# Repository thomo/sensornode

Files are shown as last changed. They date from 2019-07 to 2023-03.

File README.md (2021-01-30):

# SensorNode

A ESP8266 based solution with support for

- DS18B20 1-Wire temperature sensor
- BME280 humidity, pressure, temperature sensor (I2C) - Note: temperature is measured in-chip, so it is usually too inaccurate to measure the environment temperature
- Si7021 humidity, temperatur sensor (I2C)
- HTU21 humidity, temperatur sensor (I2C)
- LDR sensors to "measure" the brightness (analog)

The software will determine which sensors are connected. Because of the fixed I2C addresses on the sensors only one example of BME, Si7021, or HTU21 can be connected - but multiple different. Multiple 1-Wire sensors are supported. In total the number of sensors is set to 10 (`main.cpp`__MAX_SENSORS__) - but please note that each measurand counts, e.g. a BME280 counts 3x.

The software provides an configuration web page where the sensors can be enabled and an location can be specified.

The ESP will than read the sensors every 10 seconds (can be changed in ~~`main.cpp` __FETCH_SENSORS_CYCLE_SEC__~~ config dialog). The values are published via MQTT (`main.cpp` __MQTT_SERVER__). The used MQTT topic can be configured by the configuration web page (see below).

## Compile time configuration

There are some values which are only configureable on compile time (in `main.cpp`).

- DEFAULT_NODE_NAME (= F42-NODE) - used as WiFi SSID
- MQTT_SERVER (= mqtt.thomo.de) - the MQTT server, you will have to use your own :wink:
- ~~ALTITUDE (= 282.0F) - your local altitude in meters, used to adjust the pressure measurement~~ (configurable in the config dialog)
- DEFAULT_ROOT_TOPIC (= "tmp") - the standard root topic
- ~~FETCH_SENSORS_CYCLE_SEC (= 10) - fetch the sensor values every 10 seconds~~
- MAX_SENSORS (= 10) - number of supported sensors

## Runtime configuration

The runtime configuration is done by using a configuration web page served by the node. Just enter *`http://<node-ip>`*.

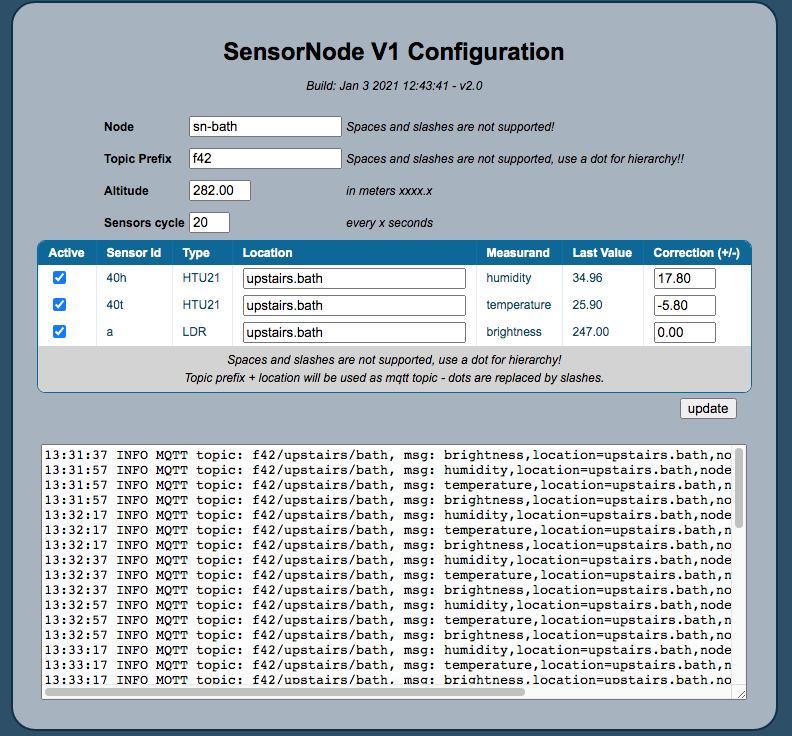
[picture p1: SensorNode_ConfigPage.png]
Configuration page


The config dialog allows you to enable/disable (aka activate) the connected sensors, only active sensor values are MQTT published.
For each sensor a location can be defined and a correction value. The correction value is add/sub from the sensor value and is used to calibrate the sensor.

*Note:* The displayed sensor value and the value published at MQTT already include the correction value.

## API

The Sensor Node offers some URIs

- `http://<node-ip>/config` - the node name, root topic, altitude, and display flag, as JSON data
- `http://<node-ip>/sensors` - the sensor data, as JSON

## MQTT Topic and Payload

The node will acquire the sensor measurements every X seconds - wether or not the sensor is enabled. It will than publish the value to the MQTT server with:

- topic: `<root topic>/<location>` - where each dot '.' in the root topic and in location is replaced by a slash.
  
  E.g.: with root topic *homebase* and sensor location *ground.kitchen* the resulting topic is `homebase/ground/kitchen`.
- payload: `<measurand>,location=<sensor location>,node=<node name>,sensor=<sensor type> value=<sensor value>`

  E.g.: for the selected DS18B20 sensor above the payload is `temperature,location=upstairs.workroom,node=f42,sensor=DS18B20 value=25.25`

## Circuit and PCB designs

### Sensors

- I2C Sensors
  - SDA -> GPIO4 (D2)
  - SCL -> GPIO5 (D1)
- 1wire
  - DATA -> GPIO0 (D3)
- LDR
  - ADC (Pin2)

### Display

- ST7735 -> ESP8266
  - 1 - RST -> RST or +3V3
  - 2 - CS  -> GPIO15 (D8)  
  - 3 - D/C -> GPIO2 (D4)
  - 4 - DIN -> GPI13 (D7)
  - 5 - CLK -> GPI14 (D5)
  - 6 - VCC -> +3V3
  - 7 - BL  -> +3V3
  - 8 - GND -> GND

__Note:__ _GPIO12 (D6) is not connected but is part of the SPI interface._

### SensorNodeUsb

It is a board to be used with the sensor node code. The board is designed to be simply plugged in an USB port.

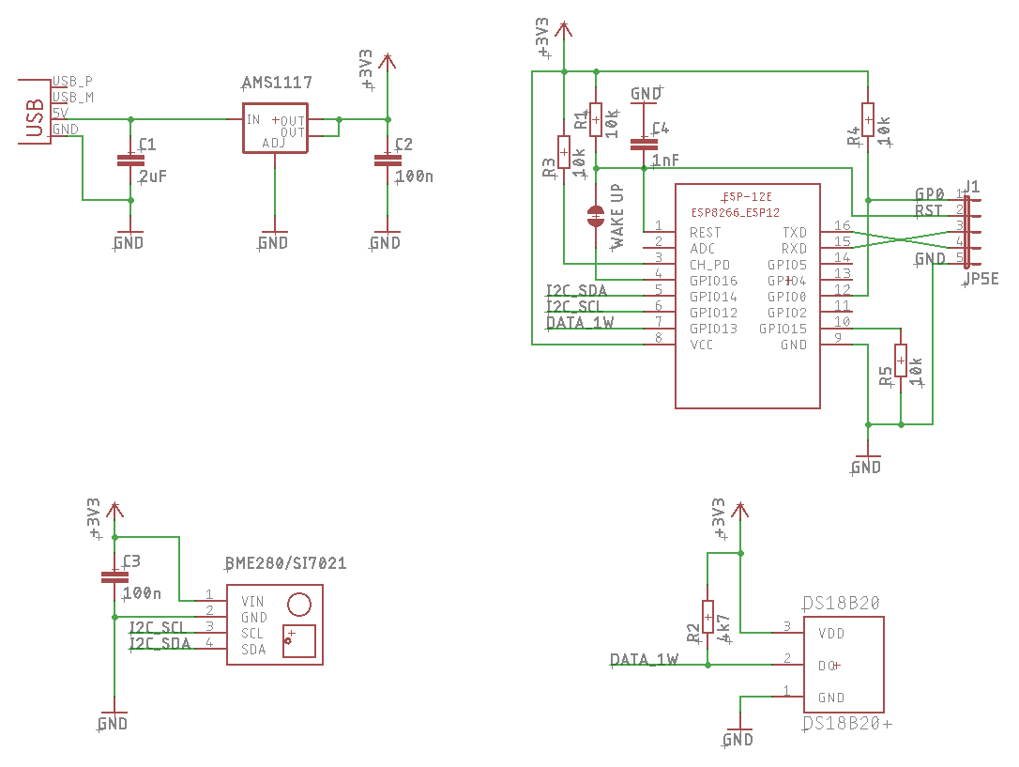
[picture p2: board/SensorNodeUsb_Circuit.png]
Circuit SensorNodeUsb circuit


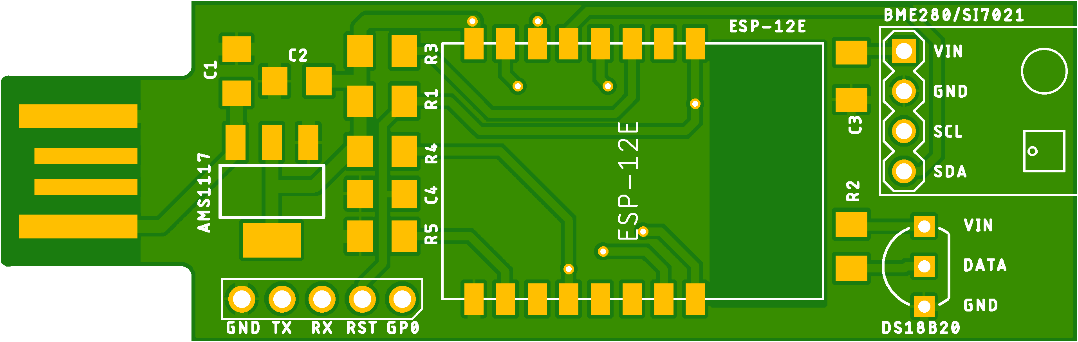
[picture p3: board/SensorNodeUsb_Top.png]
PCB top layer SensorNodeUsb PCB top layer


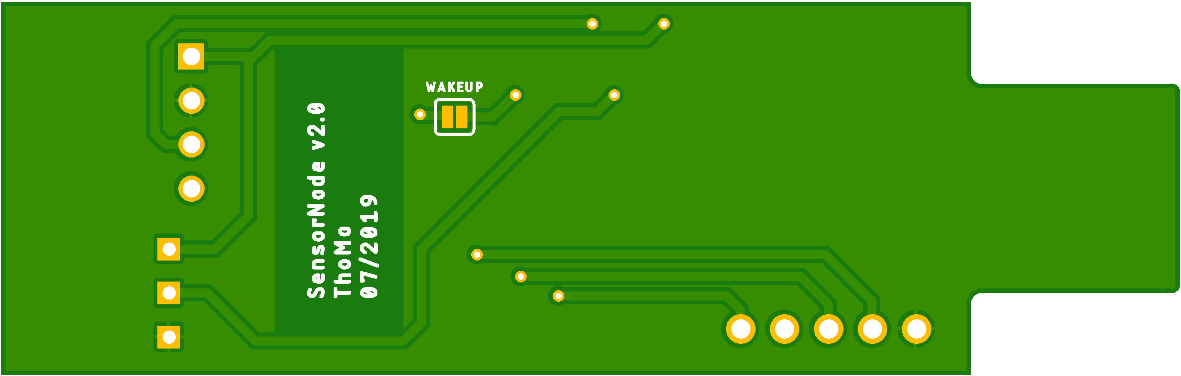
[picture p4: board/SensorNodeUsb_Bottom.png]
PCB bottom layer SensorNodeUsb PCB bottom layer


If you want to order some pcb boards you can use this link to [Aisler](https://aisler.net/p/KDLFHCIK).

### SensorNodeCat

Another board I designed to be placed in a CAT box, but it can also be used in a more general way.

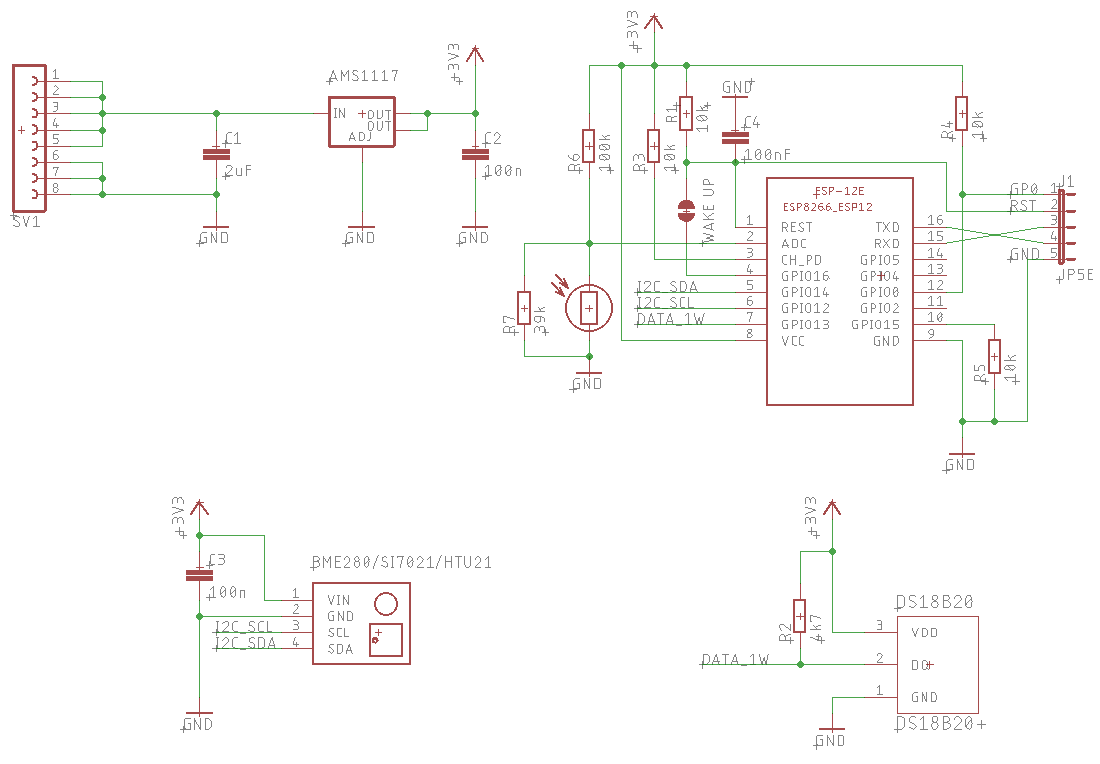
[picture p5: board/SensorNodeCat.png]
Circuit SensorNodeCat circuit


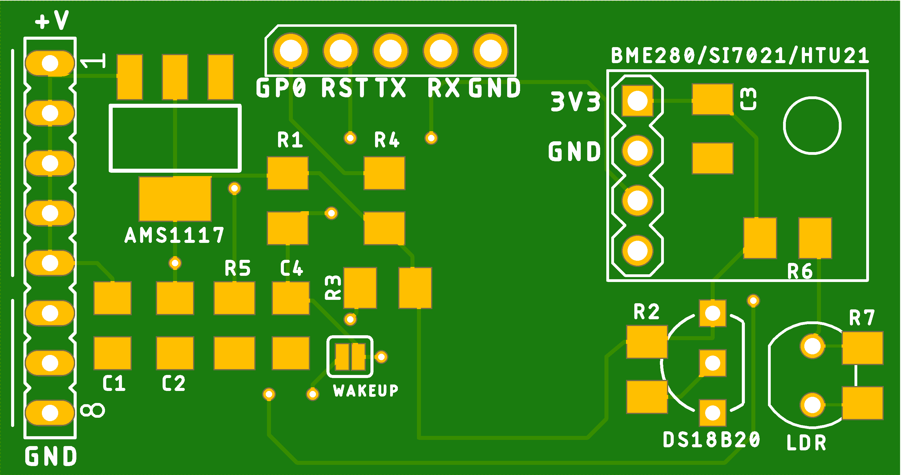
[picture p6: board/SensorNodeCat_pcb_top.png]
PCB top layer SensorNodeCat PCB top layer


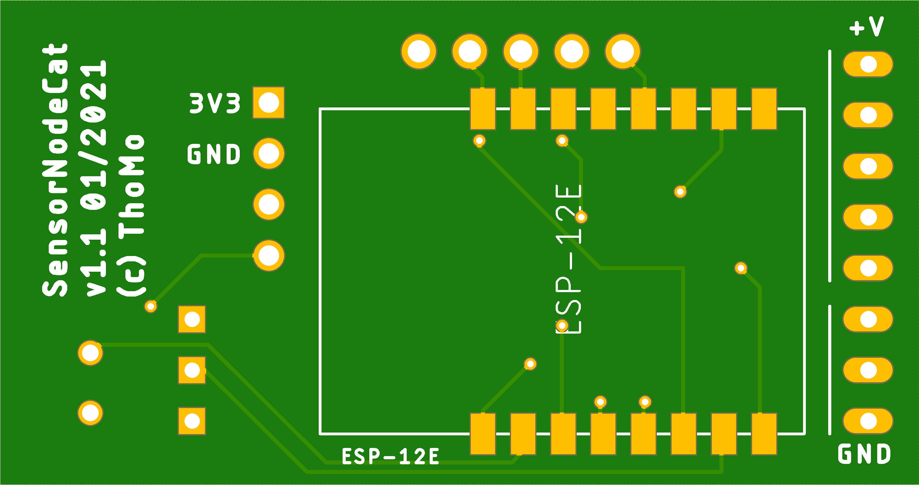
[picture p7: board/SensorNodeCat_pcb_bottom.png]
PCB bottom layer SensorNodeCat PCB bottom layer


If you want to order some pcb boards you can use this link to [Aisler](
https://aisler.net/p/CNWEPDIW).

## Fonts/Icons

- Font: [Landasans](https://www.fontspace.com/search?q=landasans)
- Icons:
  - https://iconarchive.com/search?q=weather&page=6
  - https://www.elegantthemes.com/blog/freebie-of-the-week/beautiful-flat-icons-for-free
  - http://paomedia.github.io/small-n-flat/

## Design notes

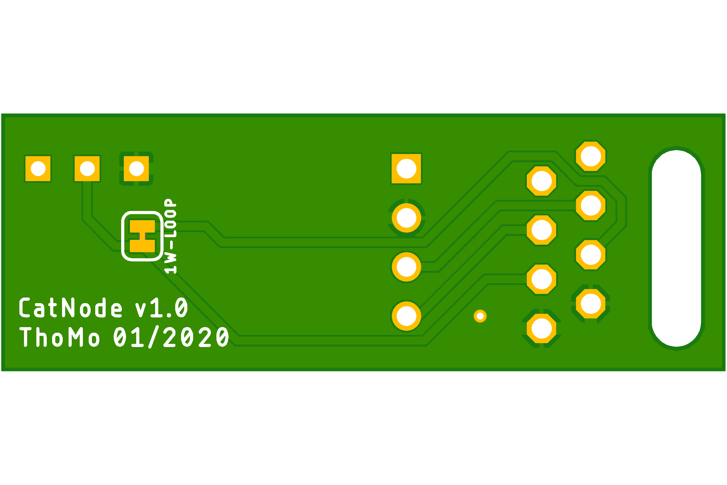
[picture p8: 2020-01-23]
board/CatNode_pcb_bottom.png

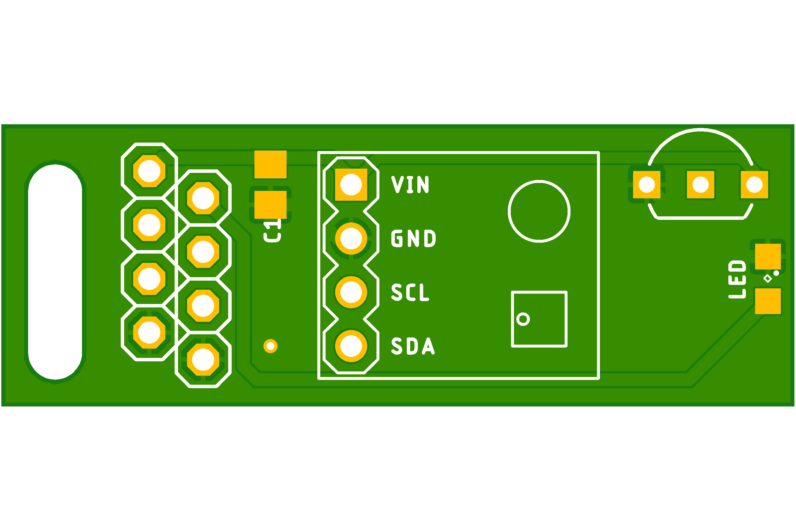
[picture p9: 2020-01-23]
board/CatNode__pcb_top.png

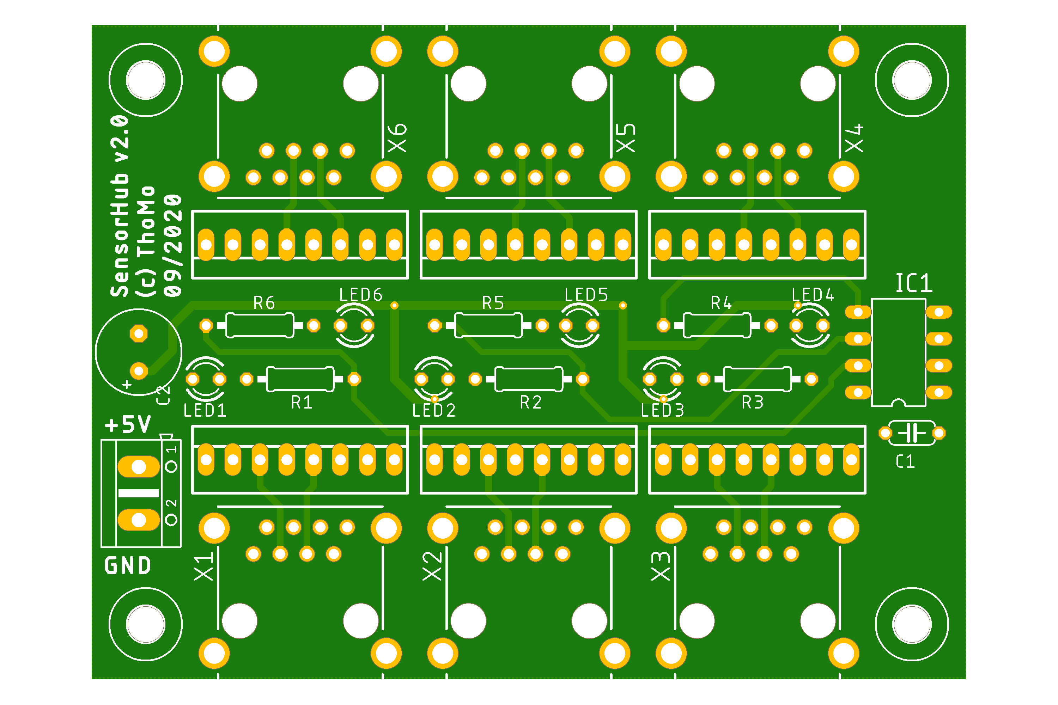
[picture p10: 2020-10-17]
board/SensorHub_pcb_top.png

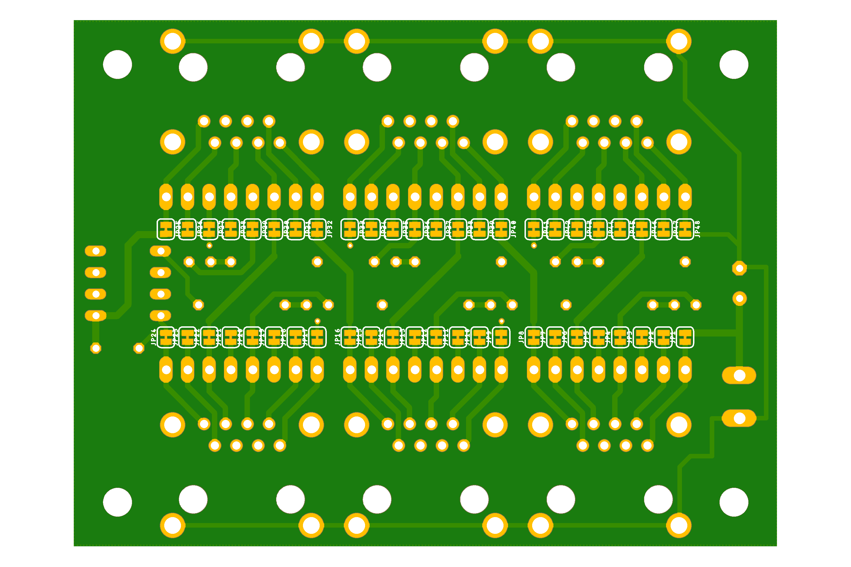
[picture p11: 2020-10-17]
board/SensorHub_pcb_bottom.png

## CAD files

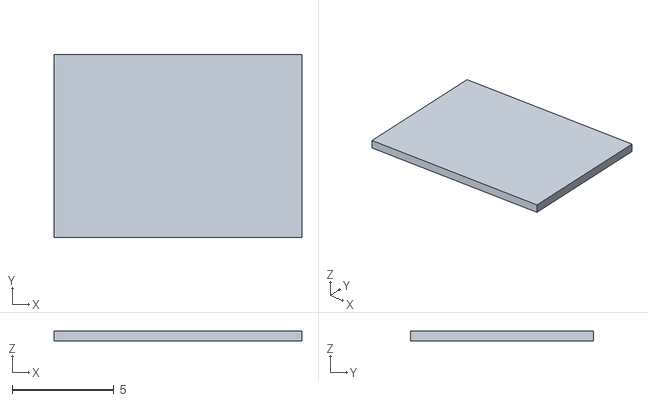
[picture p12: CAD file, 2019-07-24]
3d/usbspacer.stl
12.2 x 9.00 x 0.5

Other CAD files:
3d/usbspacer.blend

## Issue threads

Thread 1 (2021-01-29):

Quesrtions about the PCB

JPFrancoia, 2021-01-29:
Hi,

I looked at your project and it looks very good. I'm no expert at reading PCB design, so I figured I might ask you directly:

- Is there any way to link the Vin pin of the I2C sensor to a GPIO of the board (to limit power consumption) ?
- Is it possible to power the PCB with a battery?

I really like the compactness of the PCB, and the USB interface. It would be super practical to make a small sensor: no hanging wires since the I2C sensor is soldered directly on the board, and very easy to upgrade the code through USB (I can 3D print a case to just expose the usb).

Kind regards

thomo, 2021-01-30:
Hi,
1) I didn't try it but I assume it should be possible. You could just try to cut the trace above pin8 of ESP which goes to the sensors and connect the senors side to GPIO2.
2) Sure - please check the SensorNodeCat board (in folder board). It is even more compact.

JPFrancoia, 2021-01-30:
Perfect, thank you very much!

Closed 2021-01-30.

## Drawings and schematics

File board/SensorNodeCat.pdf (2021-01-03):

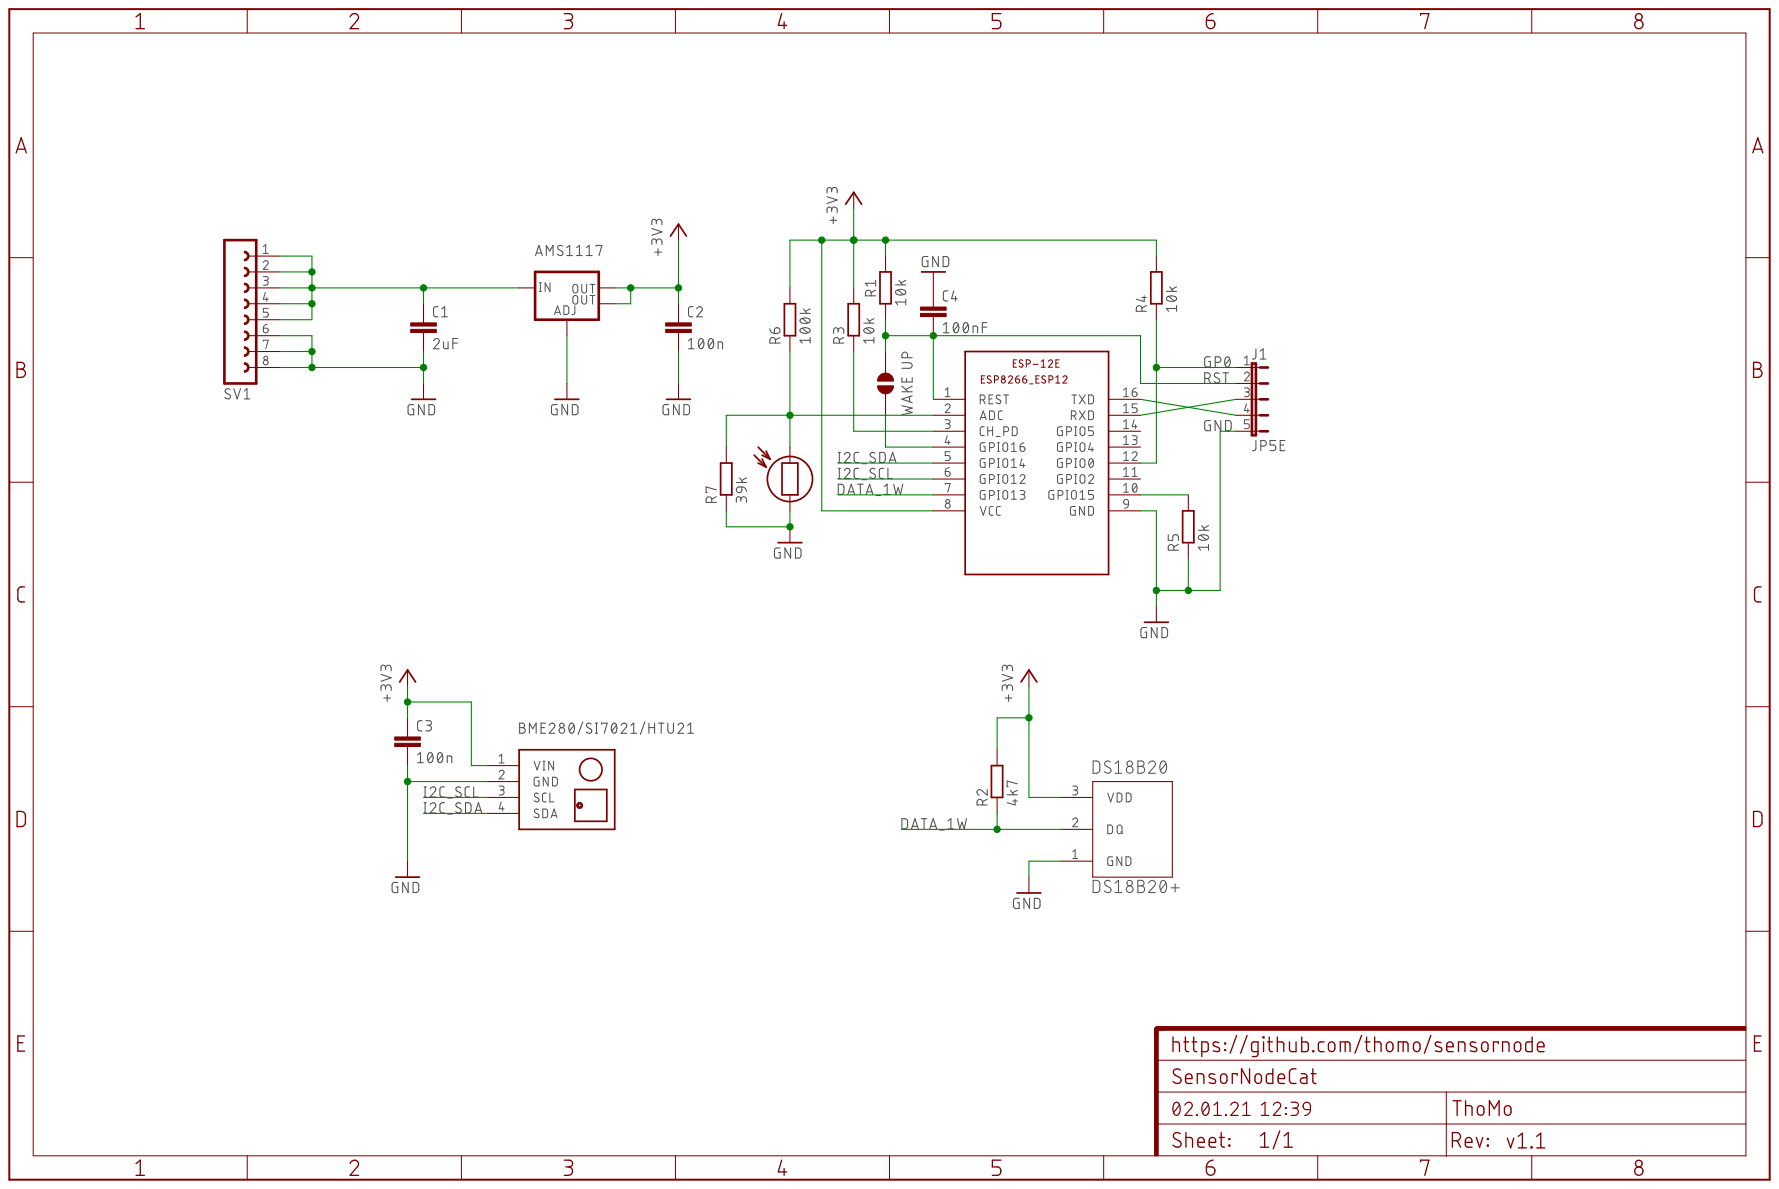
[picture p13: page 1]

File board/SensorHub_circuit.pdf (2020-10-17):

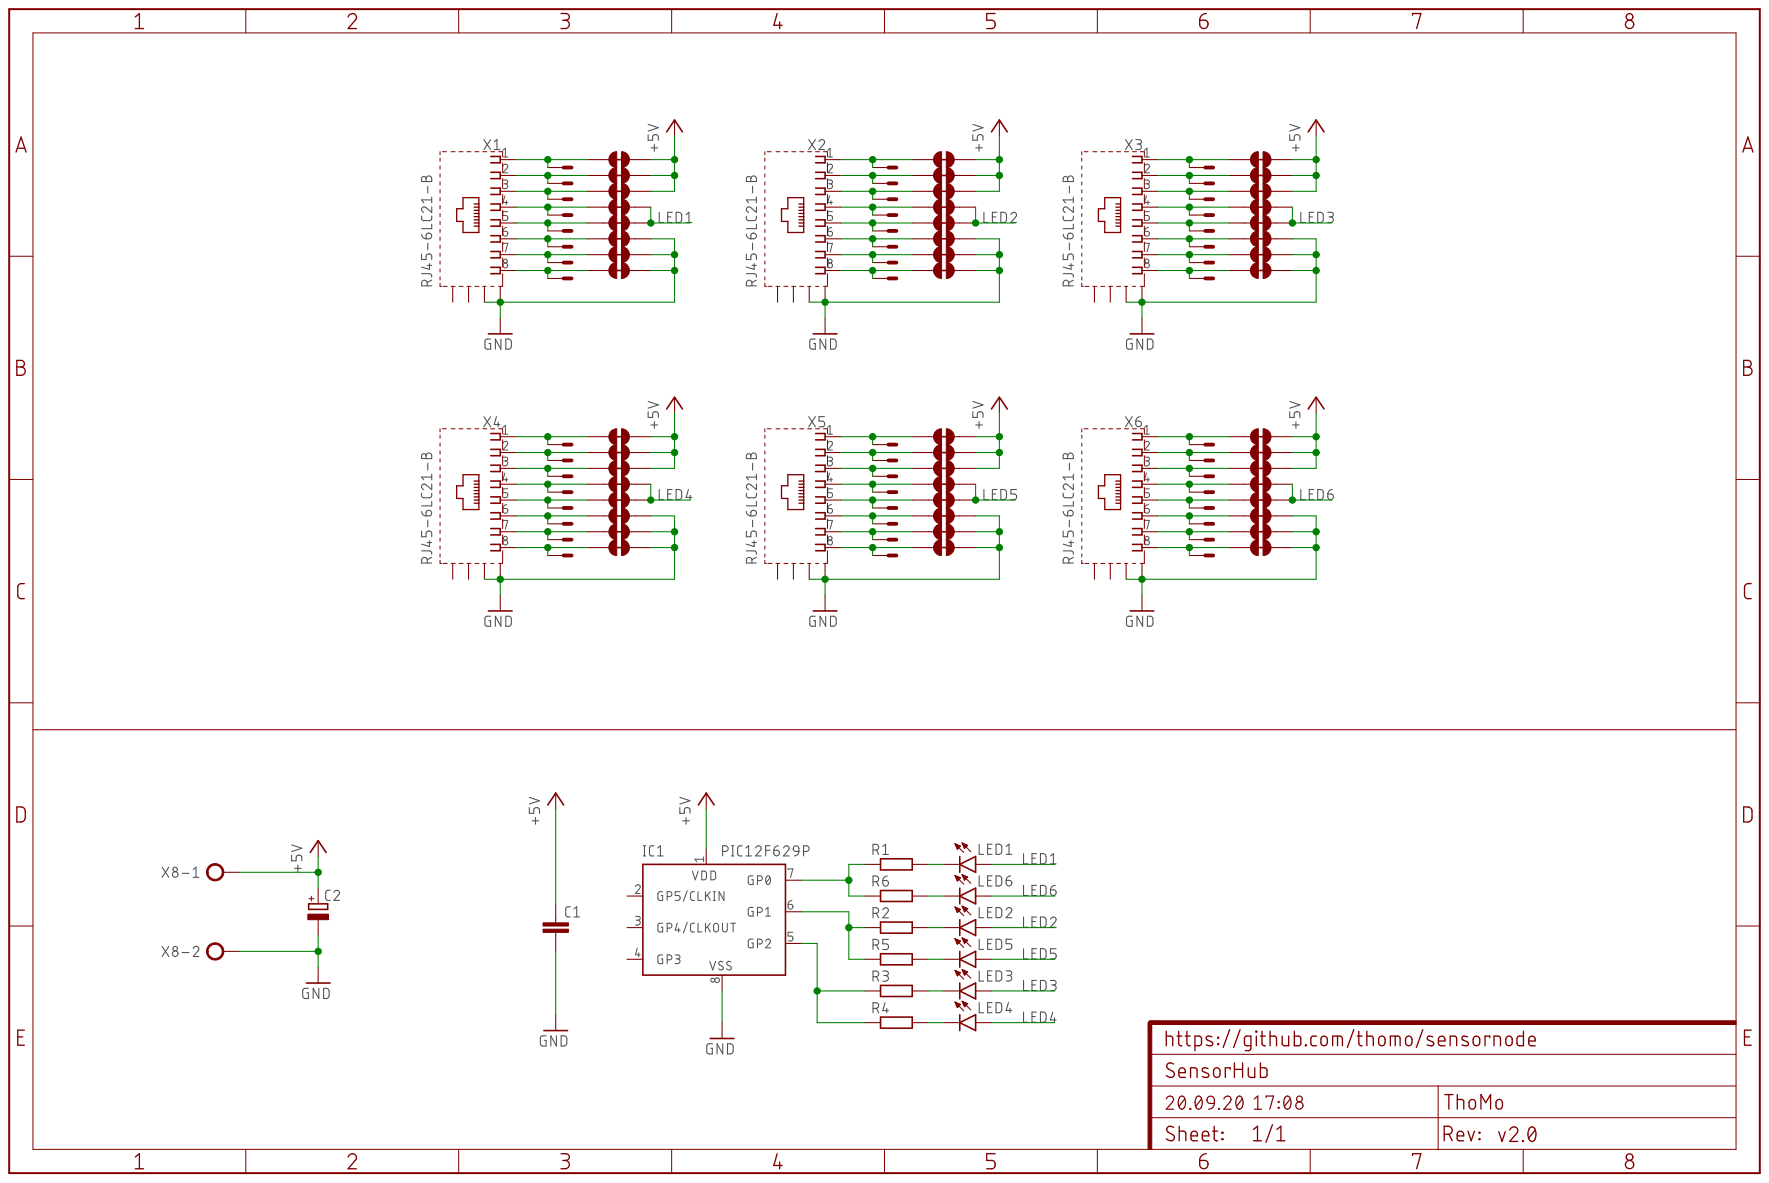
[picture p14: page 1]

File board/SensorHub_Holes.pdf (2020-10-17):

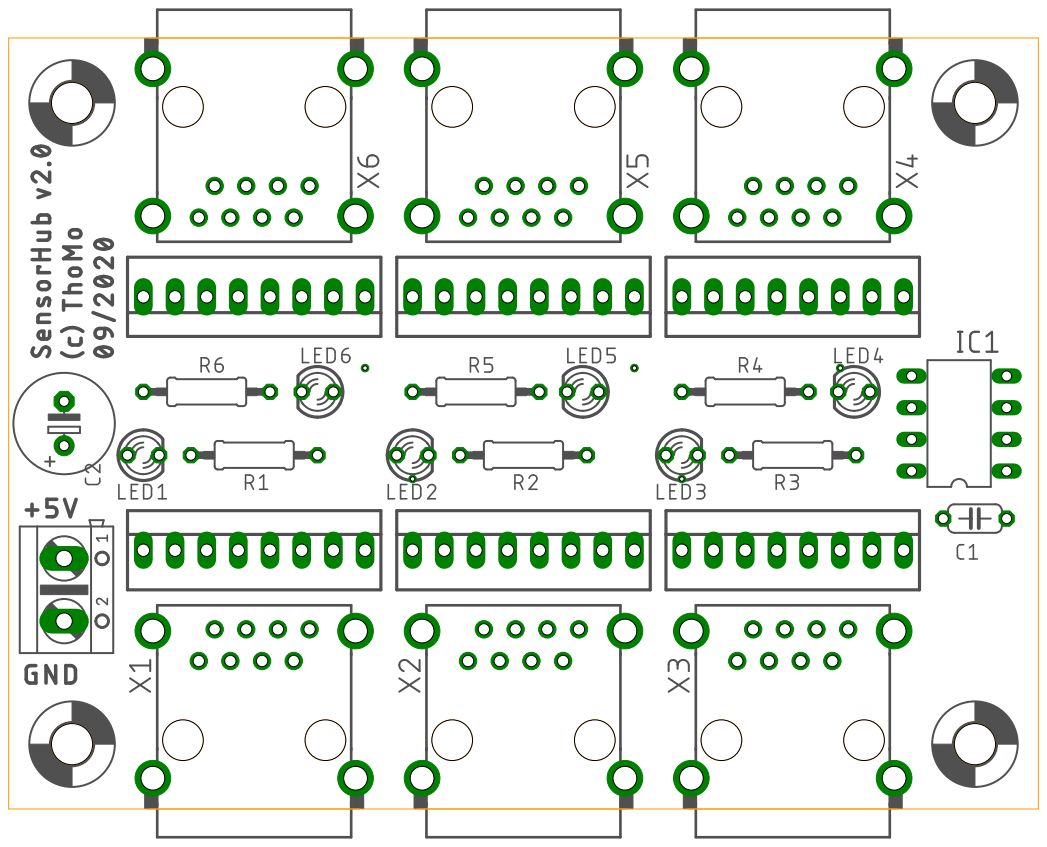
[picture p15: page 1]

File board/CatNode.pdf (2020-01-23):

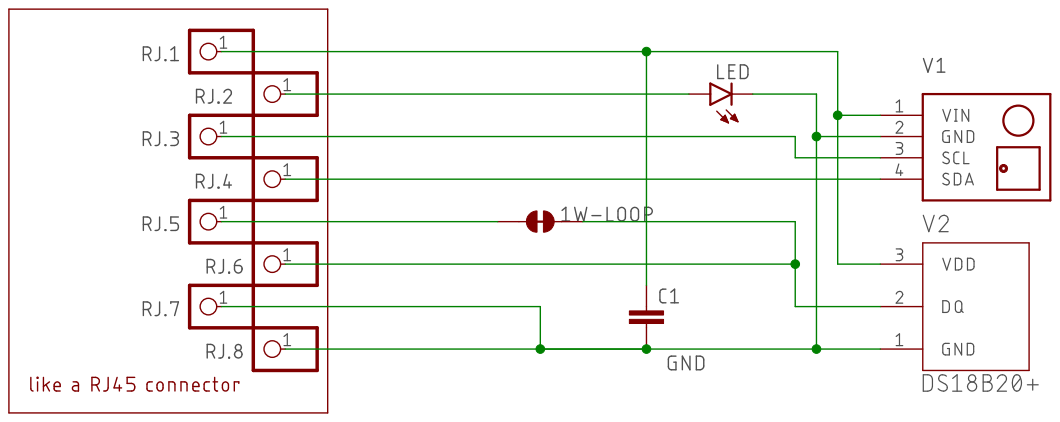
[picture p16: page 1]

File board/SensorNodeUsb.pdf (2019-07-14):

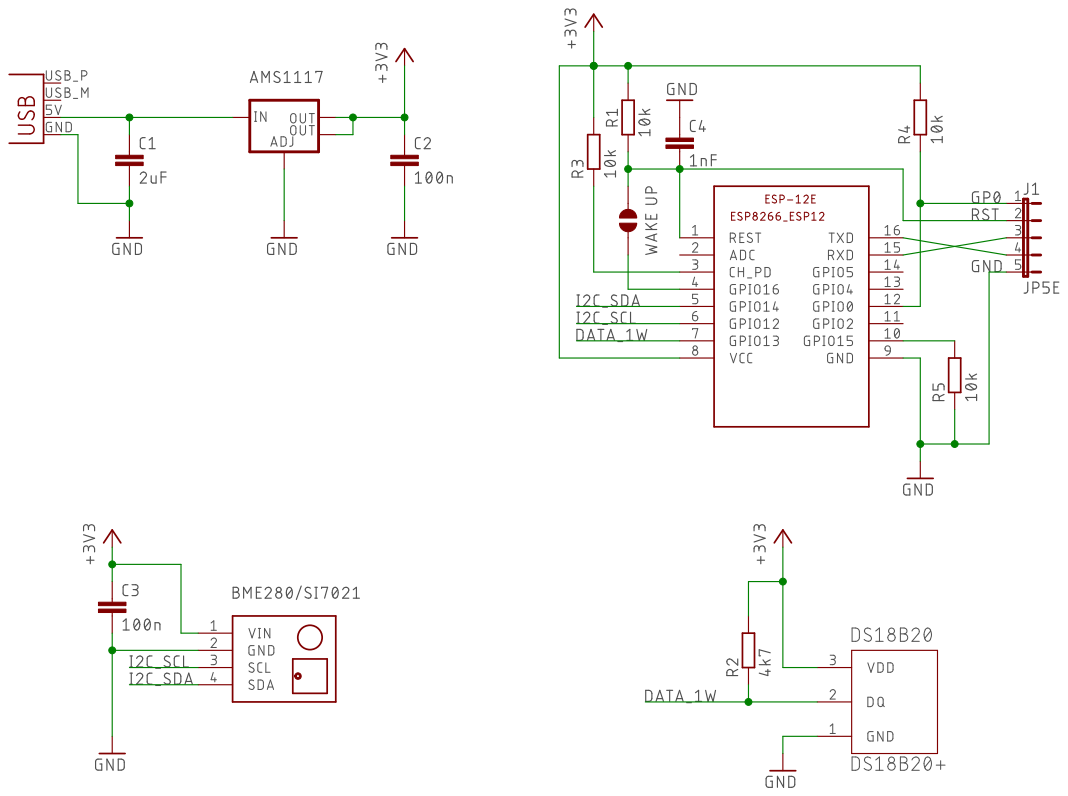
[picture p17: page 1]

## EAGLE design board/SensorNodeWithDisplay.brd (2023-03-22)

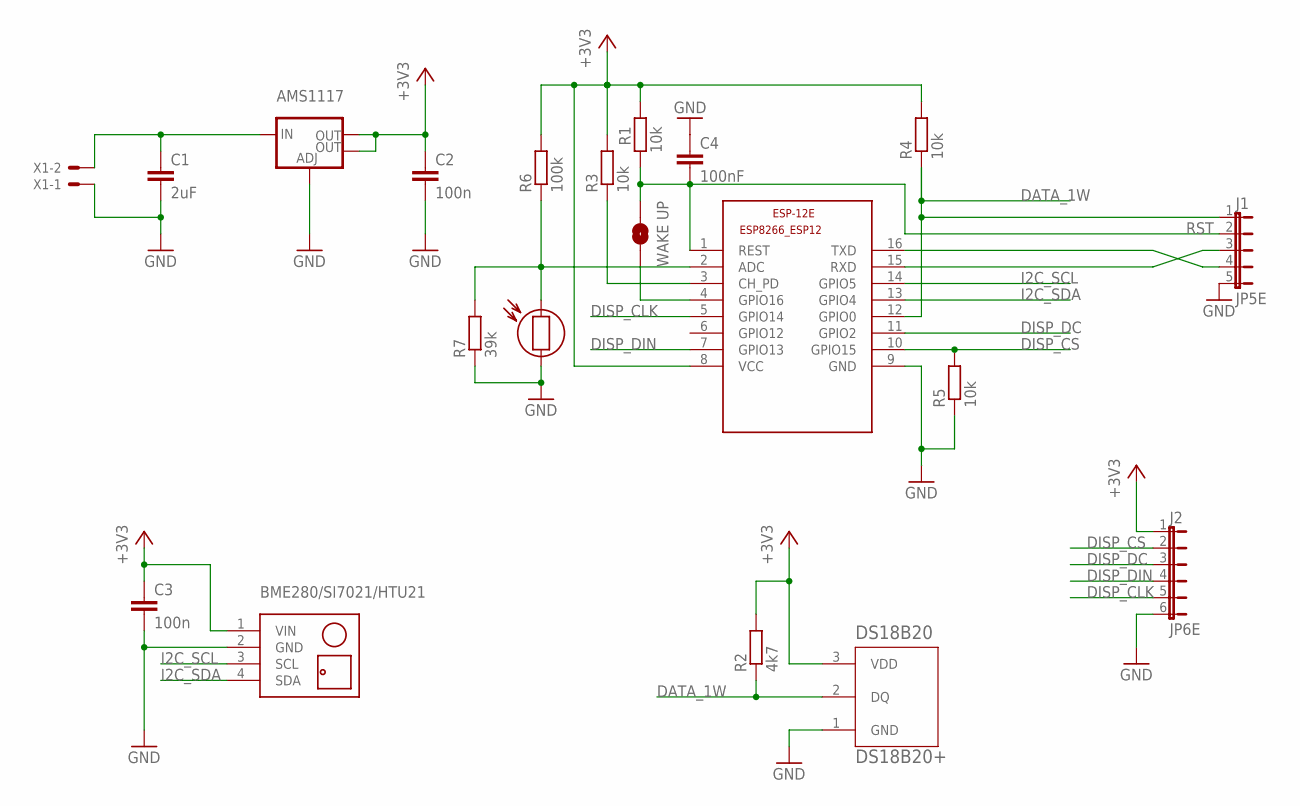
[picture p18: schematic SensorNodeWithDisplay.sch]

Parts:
AMS1117: V_REG_LM1117SOT223; SOT223
BME280/SI7021/HTU21: BME280
C1: 2uF; C1206
C2: 100n; C1206
C3: 100n; C1206K
C4: 100nF; C1206
DS18B20: DS18B20+; TO-92
ESP-12E: ESP8266-12; ESP8266-ESP12
J1: JP5E; JP5
J2: JP6E; JP6
LDR: LDR-GL55XX; GL55
R1, R3, R4, R5: 10k; M1206
R2: 4k7; M1206
R6: 100k; M1206
R7: 39k; M1206
WAKEUP: WAKE UP; SMT-JUMPER_2_NO_SILK
X1: JST-XH-02-PIN-LONG-PAD; JST-XH-02-PACKAGE-LONG-PAD

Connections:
+3V3: AMS1117.2 (OUT), AMS1117.4 (OUT), BME280/SI7021/HTU21.1 (VIN), C2.1, C3.1, DS18B20.3 (VDD), ESP-12E.8 (VCC), J2.1, R1.1, R2.2, R3.2, R4.2, R6.2
DATA_1W: DS18B20.2 (DQ), ESP-12E.12 (GPIO0), J1.1, R2.1, R4.1
DISP_CLK: ESP-12E.5 (GPIO14), J2.5
DISP_CS: ESP-12E.10 (GPIO15), J2.2, R5.2
DISP_DC: ESP-12E.11 (GPIO2), J2.3
DISP_DIN: ESP-12E.7 (GPIO13), J2.4
GND: AMS1117.1 (ADJ), BME280/SI7021/HTU21.2 (GND), C1.2, C2.2, C3.2, C4.1, DS18B20.1 (GND), ESP-12E.9 (GND), J1.5, J2.6, LDR.2, R5.1, R7.1, X1.1
I2C_SCL: BME280/SI7021/HTU21.3 (SCL), ESP-12E.14 (GPIO5)
I2C_SDA: BME280/SI7021/HTU21.4 (SDA), ESP-12E.13 (GPIO4)
unnamed: ESP-12E.15 (RXD), J1.3
unnamed: ESP-12E.4 (GPIO16), WAKEUP.1
unnamed: ESP-12E.3 (CH_PD), R3.1
unnamed: ESP-12E.16 (TXD), J1.4
unnamed: ESP-12E.2 (ADC), LDR.1, R6.1, R7.2
unnamed: AMS1117.3 (IN), C1.1, X1.2
RST: C4.2, ESP-12E.1 (REST), J1.2, R1.2, WAKEUP.2

Board: 2 copper layers, 24 parts (0 on the bottom side), 16 nets, no tracks yet.

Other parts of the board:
U$1, U$2, U$3, U$5: 3,0

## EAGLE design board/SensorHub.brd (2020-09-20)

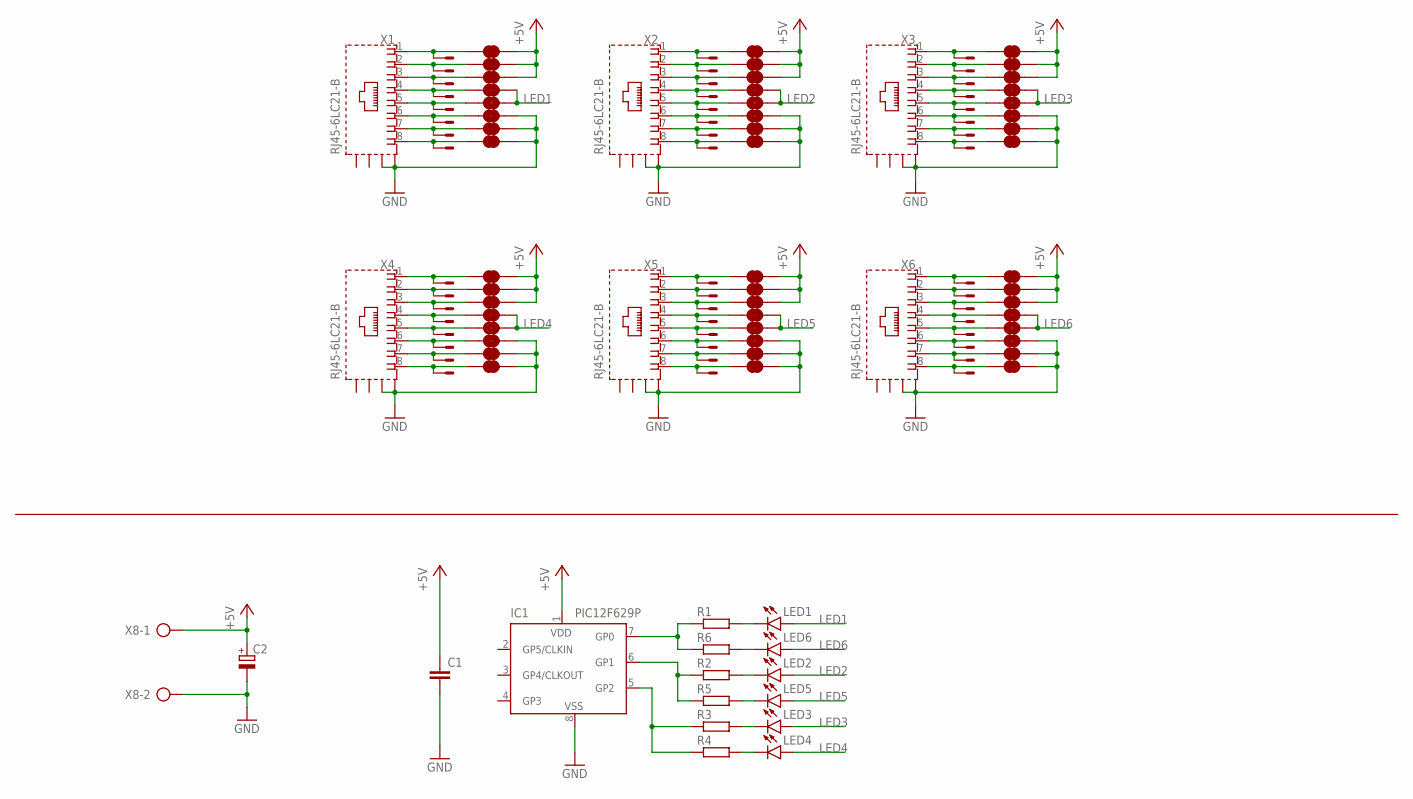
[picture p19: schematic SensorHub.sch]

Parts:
C1: C-EU050-024X044; C050-024X044
C2: CPOL-EUE3.5-8; E3,5-8
IC1: PIC12F629P; DIL8
JP1, JP2, JP3, JP4, JP5, JP6, JP7, JP8, JP9, JP10, JP11, JP12, JP13, JP14, JP15, JP16, JP17, JP18, JP19, JP20, JP21, JP22, JP23, JP24, JP25, JP26, JP27, JP28, JP29, JP30, JP31, JP32, JP33, JP34, JP35, JP36, JP37, JP38, JP39, JP40, JP41, JP42, JP43, JP44, JP45, JP46, JP47, JP48: JUMPER-SMT_2_NC_TRACE_SILK; SMT-JUMPER_2_NC_TRACE_SILK
LED1, LED2, LED3, LED4, LED5, LED6: TLLR4400; LED3MM
R1, R2, R3, R4, R5, R6: R-EU_0207/10; 0207/10
X1, X2, X3, X4, X5, X6: RJ45-6LC21-B; RJ45-SHIELD1
X1.1, X1.2, X1.3, X1.4, X1.5, X1.6: 22-23-2081
X8: AK500/2

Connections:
+5V: C1.1, C2.+, IC1.1 (VDD), JP1.2, JP2.2, JP3.2, JP9.2, JP10.2, JP11.2, JP17.2, JP18.2, JP19.2, JP25.2, JP26.2, JP27.2, JP33.2, JP34.2, JP35.2, JP41.2, JP42.2, JP43.2, X8.1
GND: C1.2, C2.-, IC1.8 (VSS), JP6.2, JP7.2, JP8.2, JP14.2, JP15.2, JP16.2, JP22.2, JP23.2, JP24.2, JP30.2, JP31.2, JP32.2, JP38.2, JP39.2, JP40.2, JP46.2, JP47.2, JP48.2, X1.S1 (S), X1.S2 (S), X2.S1 (S), X2.S2 (S), X3.S1 (S), X3.S2 (S), X4.S1 (S), X4.S2 (S), X5.S1 (S), X5.S2 (S), X6.S1 (S), X6.S2 (S), X8.2
LED1: JP4.2, JP5.2, LED1.A
LED2: JP12.2, JP13.2, LED2.A
LED3: JP20.2, JP21.2, LED3.A
LED4: JP28.2, JP29.2, LED4.A
LED5: JP36.2, JP37.2, LED5.A
LED6: JP44.2, JP45.2, LED6.A
unnamed: JP1.1, X1.1, X1.1.1
unnamed: JP2.1, X1.2, X1.1.2
unnamed: JP3.1, X1.3, X1.1.3
unnamed: JP4.1, X1.4, X1.1.4
unnamed: JP5.1, X1.5, X1.1.5
unnamed: JP6.1, X1.6, X1.1.6
unnamed: JP7.1, X1.7, X1.1.7
unnamed: JP8.1, X1.8, X1.1.8
unnamed: JP9.1, X1.2.1, X2.1
unnamed: IC1.6 (GP1), R2.1, R5.1
unnamed: LED1.K (C), R1.2
unnamed: LED2.K (C), R2.2
unnamed: LED3.K (C), R3.2
unnamed: LED6.K (C), R6.2
unnamed: LED5.K (C), R5.2
unnamed: LED4.K (C), R4.2
unnamed: JP10.1, X1.2.2, X2.2
unnamed: JP11.1, X1.2.3, X2.3
unnamed: JP12.1, X1.2.4, X2.4
unnamed: IC1.7 (GP0), R1.1, R6.1
unnamed: JP13.1, X1.2.5, X2.5
unnamed: IC1.5 (GP2), R3.1, R4.1
unnamed: JP14.1, X1.2.6, X2.6
unnamed: JP15.1, X1.2.7, X2.7
unnamed: JP16.1, X1.2.8, X2.8
unnamed: JP17.1, X1.3.1, X3.1
unnamed: JP18.1, X1.3.2, X3.2
unnamed: JP19.1, X1.3.3, X3.3
unnamed: JP20.1, X1.3.4, X3.4
unnamed: JP21.1, X1.3.5, X3.5
unnamed: JP22.1, X1.3.6, X3.6
unnamed: JP23.1, X1.3.7, X3.7
unnamed: JP24.1, X1.3.8, X3.8
unnamed: JP25.1, X1.4.1, X4.1
unnamed: JP26.1, X1.4.2, X4.2
unnamed: JP27.1, X1.4.3, X4.3
unnamed: JP28.1, X1.4.4, X4.4
unnamed: JP29.1, X1.4.5, X4.5
unnamed: JP30.1, X1.4.6, X4.6
unnamed: JP31.1, X1.4.7, X4.7
unnamed: JP32.1, X1.4.8, X4.8
unnamed: JP33.1, X1.5.1, X5.1
unnamed: JP34.1, X1.5.2, X5.2
unnamed: JP35.1, X1.5.3, X5.3
unnamed: JP36.1, X1.5.4, X5.4
unnamed: JP37.1, X1.5.5, X5.5
unnamed: JP38.1, X1.5.6, X5.6
unnamed: JP39.1, X1.5.7, X5.7
unnamed: JP40.1, X1.5.8, X5.8
unnamed: JP41.1, X1.6.1, X6.1
unnamed: JP42.1, X1.6.2, X6.2
unnamed: JP43.1, X1.6.3, X6.3
unnamed: JP44.1, X1.6.4, X6.4
unnamed: JP45.1, X1.6.5, X6.5
unnamed: JP46.1, X1.6.6, X6.6
unnamed: JP47.1, X1.6.7, X6.7
unnamed: JP48.1, X1.6.8, X6.8

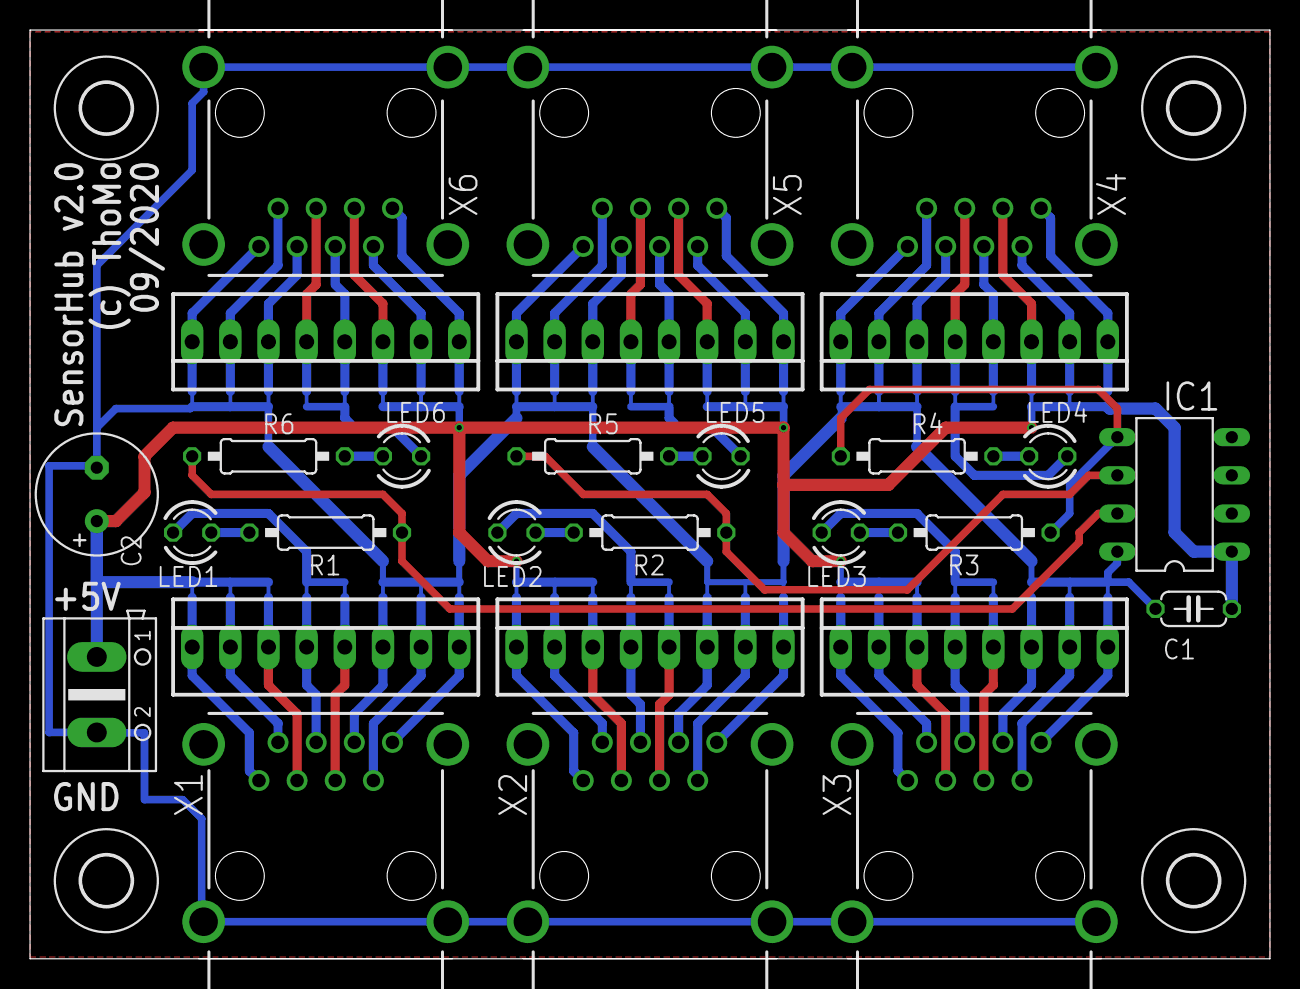
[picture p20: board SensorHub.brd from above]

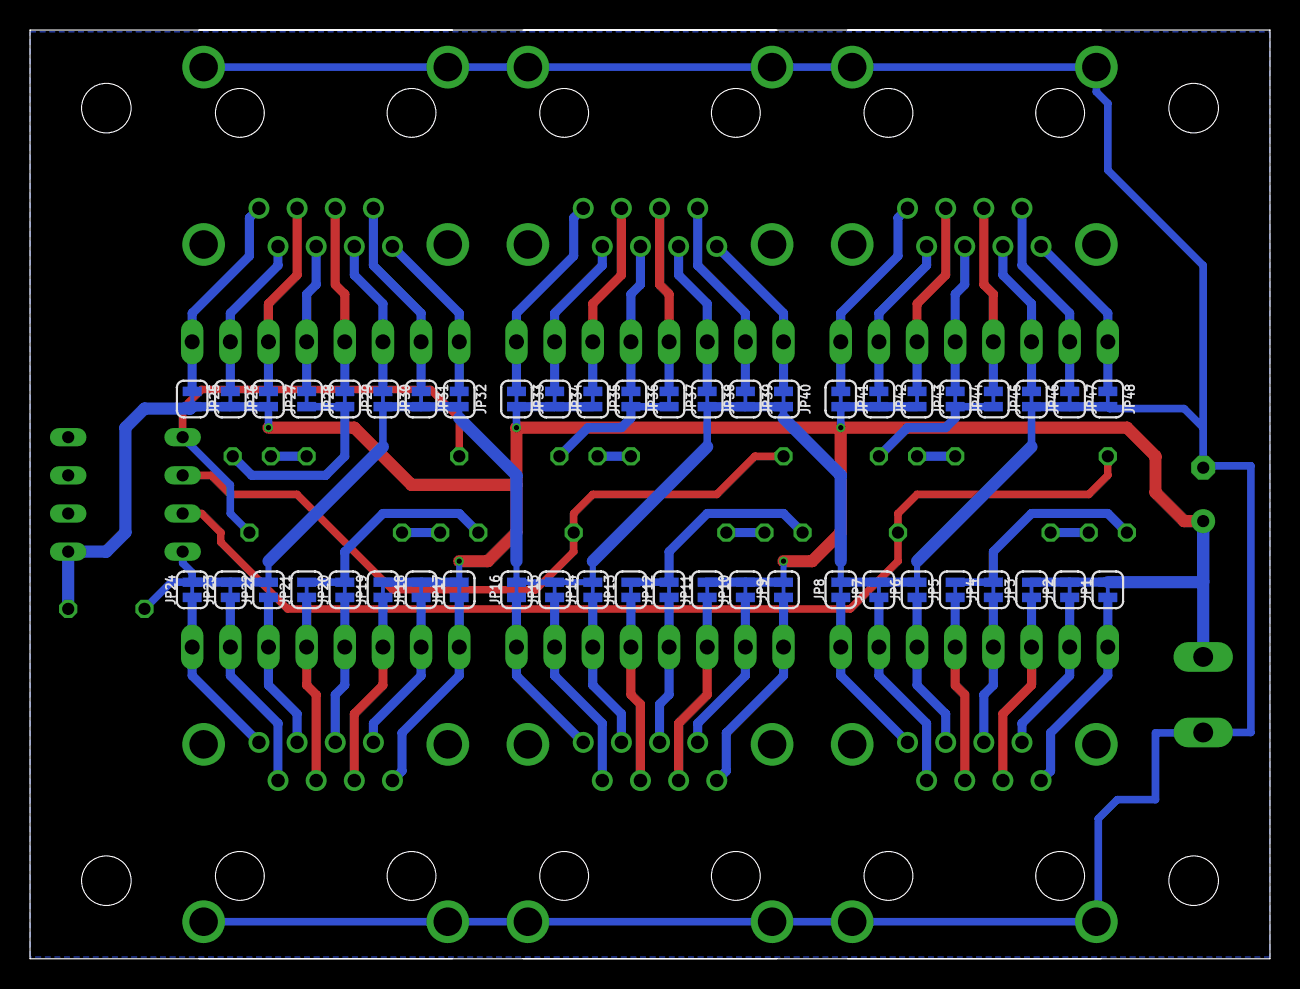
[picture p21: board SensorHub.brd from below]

Board: 2 copper layers, 82.5 x 61.8 mm, 80 parts (48 on the bottom side), 65 nets.

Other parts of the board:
U$1, U$2, U$3, U$4: 3,3

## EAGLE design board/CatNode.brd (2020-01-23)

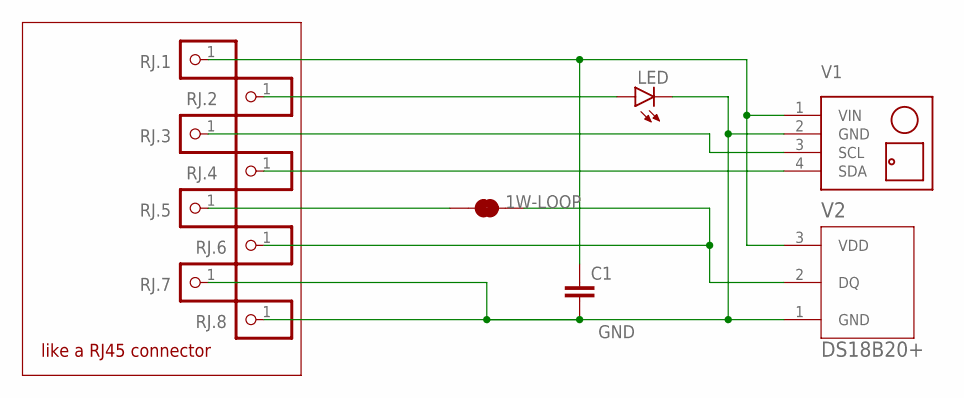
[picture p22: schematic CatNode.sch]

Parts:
1W-LOOP: JUMPER-SMT_2_NC_TRACE_SILK; SMT-JUMPER_2_NC_TRACE_SILK
C1: C-EUC0805; C0805
LED: LEDSML0805; SML0805
RJ.1, RJ.2, RJ.3, RJ.4, RJ.5, RJ.6, RJ.7, RJ.8: PINHD-1X1; 1X01
V1: TEMP-HUM-PRES-BME280
V2: DS18B20+; TO-92

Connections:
GND: C1.2, LED.C, RJ.7.1, RJ.8.1, V1.2 (GND), V2.1 (GND)
unnamed: C1.1, RJ.1.1, V1.1 (VIN), V2.3 (VDD)
unnamed: RJ.4.1, V1.4 (SDA)
unnamed: LED.A, RJ.2.1
unnamed: RJ.3.1, V1.3 (SCL)
unnamed: 1W-LOOP.1, RJ.5.1
unnamed: 1W-LOOP.2, RJ.6.1, V2.2 (DQ)

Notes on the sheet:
like a RJ45 connector

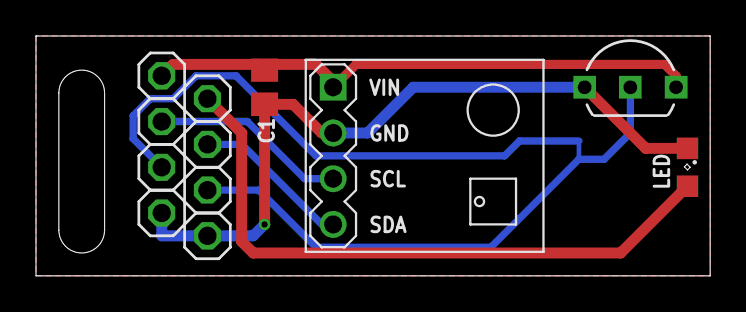
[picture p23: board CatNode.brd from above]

Board: 2 copper layers, 37.5 x 13.3 mm, 13 parts (1 on the bottom side), 7 nets.

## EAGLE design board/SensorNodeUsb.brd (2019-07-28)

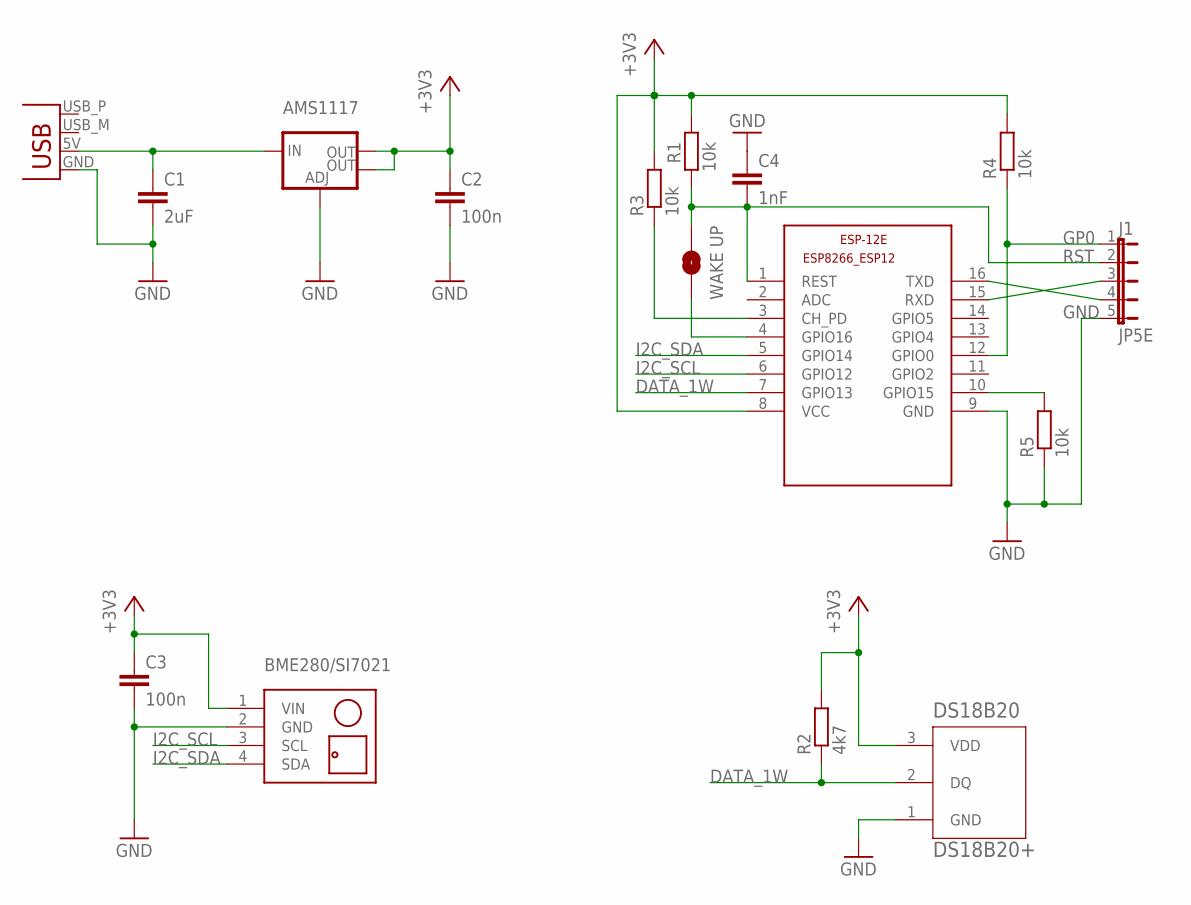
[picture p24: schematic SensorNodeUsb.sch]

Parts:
AMS1117: V_REG_LM1117SOT223; SOT223
BME280/SI7021: TEMP-HUM-PRES-BME280
C1: 2uF; C1206
C2: 100n; C1206
C3: 100n; C1206K
C4: 1nF; C1206
DS18B20: DS18B20+; TO-92
ESP-12E: ESP8266-12; ESP8266-ESP12
J1: JP5E; JP5
R1, R3, R4, R5: 10k; M1206
R2: 4k7; M1206
WAKEUP: WAKE UP; SMT-JUMPER_2_NO_SILK
X2: USBPCB; USB-A-PCB

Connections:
+3V3: AMS1117.2 (OUT), AMS1117.4 (OUT), BME280/SI7021.1 (VIN), C2.1, C3.1, DS18B20.3 (VDD), ESP-12E.8 (VCC), R1.1, R2.2, R3.2, R4.2
DATA_1W: DS18B20.2 (DQ), ESP-12E.7 (GPIO13), R2.1
GND: AMS1117.1 (ADJ), BME280/SI7021.2 (GND), C1.2, C2.2, C3.2, C4.1, DS18B20.1 (GND), ESP-12E.9 (GND), J1.5, R5.1, X2.GND
GP0: ESP-12E.12 (GPIO0), J1.1, R4.1
I2C_SCL: BME280/SI7021.3 (SCL), ESP-12E.6 (GPIO12)
I2C_SDA: BME280/SI7021.4 (SDA), ESP-12E.5 (GPIO14)
unnamed: ESP-12E.15 (RXD), J1.3
unnamed: ESP-12E.4 (GPIO16), WAKEUP.1
unnamed: ESP-12E.3 (CH_PD), R3.1
unnamed: ESP-12E.16 (TXD), J1.4
unnamed: AMS1117.3 (IN), C1.1, X2.5V (VBUS)
unnamed: ESP-12E.10 (GPIO15), R5.2
RST: C4.2, ESP-12E.1 (REST), J1.2, R1.2, WAKEUP.2

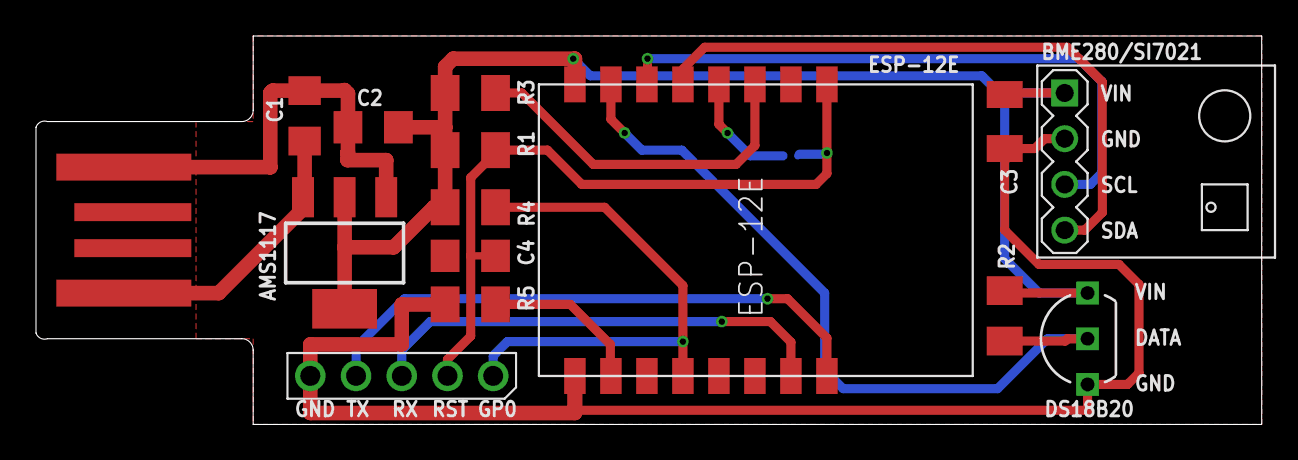
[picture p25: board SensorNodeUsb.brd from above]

Board: 2 copper layers, 68.1 x 21.6 mm, 16 parts (1 on the bottom side), 13 nets.

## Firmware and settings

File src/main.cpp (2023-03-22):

#include <Arduino.h>
#include <ArduinoOTA.h>

#include <ESP8266WiFi.h>          //ESP8266 Core WiFi Library (you most likely already have this in your sketch)

#include <DNSServer.h>            //Local DNS Server used for redirecting all requests to the configuration portal
#include <ESP8266WebServer.h>     //Local WebServer used to serve the configuration portal
#include <WiFiManager.h>          //https://github.com/tzapu/WiFiManager WiFi Configuration Magic
#include <ezTime.h>
#include <PubSubClient.h>

#define REQUIRESNEW false
#define REQUIRESALARMS false
#include <OneWire.h>
#include <DallasTemperature.h>

#include <Adafruit_BME280.h>
#include <Adafruit_Si7021.h>
#include <Adafruit_HTU21DF.h>

#include <FS.h>
#include <LittleFS.h>

#include <Ticker.h>
#include <TFT_eSPI.h> // Hardware-specific library

#include "Landasans36.h"
#include "Landasans48.h"
#define FONT_MIDDLE Landasans36
#define FONT_LARGE Landasans48

// +++++++++++++++++++
const char COMPILE_INFO[] PROGMEM = {__DATE__ " " __TIME__ " - v2.1"};
// +++++++++++++++++++

// set SENSORNODE_VERSION in platformio.ini
#ifndef SENSORNODE_VERSION
#define SENSORNODE_VERSION 1
#endif

#define DEFAULT_NODE_NAME "F42-NODE"
#define MQTT_SERVER "mqtt.thomo.de"
#define MY_NTP_SERVER "ntp.thomo.de"

#define DEFAULT_ROOT_TOPIC "tmp"

#define SENSORNODE_WITH_DISPLAY_VERSION 2
#define ANALOG_SENSOR_ADDR "a"
// +++++++++++++++++++

#include "weather.h"
#define DISP_GRID 0


// +++++++++++++++++++
#if SENSORNODE_VERSION >= SENSORNODE_WITH_DISPLAY_VERSION
#define ONE_WIRE_PIN 0
#define I2C_SDA_PIN  4
#define I2C_SCL_PIN  5
#else
#define ONE_WIRE_PIN 13
#define I2C_SDA_PIN  14
#define I2C_SCL_PIN  12
#endif


const String CONFIG_HTML = "/config.html";
const String CONFIG_FILE = "/config.cfg";
#define MAX_SENSORS 10

#define SIZE_JSON_ONE_SENSOR   (sizeof("'123456789012345678901234567890':{'enabled':1,'location':'123456789012345678901234567890','type':'123456789012345678901234567890','measurand':'123456789012345678901234567890','value':'12345678901234567890','correction':'1234567','show':1},"))
#define SIZE_JSONV_SENSORS     (SIZE_JSON_ONE_SENSOR * MAX_SENSORS)
#define SIZE_JSON_BUFFER       (sizeof("{") + SIZE_JSONV_SENSORS + sizeof("}"))
#define SIZE_WEBSENDBUFFER     (SIZE_JSON_BUFFER)

#define PAYLOAD_BUFFER_SIZE    (1024+20+20+MAX_SENSORS*40) 

#define FIXED_FONT 2

#define MYDEBUG 0
#define debug_print(line) \
            do { if (MYDEBUG) Serial.print(line); } while (0)
#define debug_println(line) \
            do { if (MYDEBUG) Serial.println(line); } while (0)
#define debug_printf(frmt, ...) \
            do { if (MYDEBUG) Serial.printf(frmt, __VA_ARGS__); } while (0)

// --- update cadence ---
uint16_t updateSensorsTimeout = 30;
uint16_t updateWeatherForecastTimeout = 5*60;

// --- SENSORS ---
// Setup a oneWire instance to communicate with any OneWire devices (not just Maxim/Dallas temperature ICs)
OneWire oneWire(ONE_WIRE_PIN);

// Pass our oneWire reference to Dallas Temperature. 
DallasTemperature dsSensors(&oneWire);
uint8_t oneWireDeviceCount = 0;

String bmeAddr = "";
Adafruit_BME280 bme; // I2C

String si70xxAddr = "";
Adafruit_Si7021 si70xx = Adafruit_Si7021(); // I2C

String htu21Addr = "";
Adafruit_HTU21DF htu21 = Adafruit_HTU21DF(); // I2C

// --- Display --- 
#if SENSORNODE_VERSION >= SENSORNODE_WITH_DISPLAY_VERSION
boolean hasDisplay = true;
#else
boolean hasDisplay = false;
#endif
TFT_eSPI tft = TFT_eSPI();

// --- Network ---
WiFiManager wifiManager;
ESP8266WebServer espServer(80);
WiFiClient espClient;
PubSubClient mqttClient(espClient);
Timezone myTZ;

WeatherClient wc = WeatherClient(&espClient);

char webSendBuffer[SIZE_WEBSENDBUFFER] = "";

String configHtml = "";
String nodeName = DEFAULT_NODE_NAME;
String rootTopic = DEFAULT_ROOT_TOPIC;
float nodeAltitude = 282.0f;

String showSensor = "";

struct SensorData {
  bool enabled;
  DeviceAddress addr;
  String id;
  String type;
  String location;
  String topic;
  String measurand;
  String value;
  float correction;
};

SensorData tmpSensor = { 
  .enabled =false,
  .addr = {0}, 
  .id="", 
  .type="", 
  .location="", 
  .topic="", 
  .measurand="", 
  .value="",
  .correction=0.0f
};

SensorData sensors[MAX_SENSORS]; 
// log buffer
#define LOGLEVEL_DEBUG 3
#define LOGLEVEL_INFO 2
#define LOGLEVEL_WARN 1
#define LOGLEVEL_ERROR 0

#define LOGLINE_LENGTH (128-3-1)
struct LogLine {
  uint8_t timestamp[3]; // hh|mm|ss
  uint8_t level; // ERROR,WARN,INFO,DEBUG
  char message[LOGLINE_LENGTH];
};
// 1k = 8 lines
char logbuf[LOGLINE_LENGTH];
#define LOGLINE_CNT (8 * 5)
LogLine logs[LOGLINE_CNT];
int8_t lastLogLine = LOGLINE_CNT - 1;
int32_t lastLogId = -1;

void logPrefix(uint8_t level) {
  ++lastLogLine;
  ++lastLogId;
  if (lastLogLine >= LOGLINE_CNT) lastLogLine = 0;
  logs[lastLogLine].timestamp[0] = myTZ.hour();
  logs[lastLogLine].timestamp[1] = myTZ.minute();
  logs[lastLogLine].timestamp[2] = myTZ.second();
  logs[lastLogLine].level = level;
}

void log(uint8_t level, const char *msg) {
  logPrefix(level);  
  Serial.println(msg);
  strlcpy(logs[lastLogLine].message, msg, LOGLINE_LENGTH); 
}

void log(uint8_t level, const __FlashStringHelper *msg) {
  logPrefix(level);  
  Serial.println(msg);
  strncpy_P(logs[lastLogLine].message, (const char *) msg, LOGLINE_LENGTH);
  logs[lastLogLine].message[LOGLINE_LENGTH-1] = '\0';
}
// ------------------------------------------------------------------------------------------------

uint16_t read16(fs::File &f) {
  uint16_t result;
  ((uint8_t *)&result)[0] = f.read(); // LSB
  ((uint8_t *)&result)[1] = f.read(); // MSB
  return result;
}

uint32_t read32(fs::File &f) {
  uint32_t result;
  ((uint16_t *)&result)[0] = read16(f); // LSB
  ((uint16_t *)&result)[1] = read16(f); // MSB
  return result;
}

void drawBmp(TFT_eSPI &tft, const char *filename, int16_t x, int16_t y) {

  if ((x >= tft.width()) || (y >= tft.height()))
    return;

  fs::File bmpFS;
  if (LittleFS.begin()) {
    // debug_println("Init LittleFS - successful.");
  } else {
    Serial.println(F("Error while init LittleFS."));
    return;
  }

  // Open requested file on SD card
  bmpFS = LittleFS.open(filename, "r");

  if (!bmpFS) {
    Serial.printf("File not found: %s\n", filename);
    return;
  }

  uint32_t seekOffset;
  uint16_t w, h, row;
  uint8_t r, g, b;

  if (read16(bmpFS) == 0x4D42) {
    read32(bmpFS); // size
    read32(bmpFS); // reserved
    seekOffset = read32(bmpFS); 
    read32(bmpFS);
    w = read32(bmpFS);
    h = read32(bmpFS);
    uint32_t i;
    if ((i = read16(bmpFS)) != 1) {
      Serial.printf("Wrong number of color planes (exp. 1): %d\n", i);
      Serial.println("BMP format not recognized.");
    } else if ((i = read16(bmpFS)) != 24) {
      Serial.printf("Wrong number bits per pixel (exp. 24): %d\n", i);
      Serial.println("BMP format not recognized.");
    } else if((i = read32(bmpFS)) != 0) {
      Serial.printf("Compression not supported: %d\n", i);
      Serial.println("BMP format not recognized.");

    } else {
      y += h - 1;

      bool oldSwapBytes = tft.getSwapBytes();
      tft.setSwapBytes(true);
      bmpFS.seek(seekOffset);

      uint16_t padding = (4 - ((w * 3) & 3)) & 3;
      uint8_t lineBuffer[w * 3 + padding];

      for (row = 0; row < h; row++)
      {

        bmpFS.read(lineBuffer, sizeof(lineBuffer));
        uint8_t *bptr = lineBuffer;
        uint16_t *tptr = (uint16_t *)lineBuffer;
        // Convert 24 to 16 bit colours
        for (uint16_t col = 0; col < w; col++)
        {
          b = *bptr++;
          g = *bptr++;
          r = *bptr++;
          *tptr++ = ((r & 0xF8) << 8) | ((g & 0xFC) << 3) | (b >> 3);
        }

        // Push the pixel row to screen, pushImage will crop the line if needed
        // y is decremented as the BMP image is drawn bottom up
        tft.pushImage(x, y--, w, 1, (uint16_t *)lineBuffer);
      }
      tft.setSwapBytes(oldSwapBytes);
      // Serial.print("Loaded in "); Serial.print(millis() - startTime);
      // Serial.println(" ms");
    }
  } else {
    Serial.println("Header don't match 0x4D42");
  }
  bmpFS.close();
  LittleFS.end();
}

void display(TFT_eSPI &tft, const char* inTemp, const char* outTemp, const char* icon, const char* timebuf, const char* datebuf) {
  tft.fillScreen(TFT_WHITE);
  tft.setTextSize(1);
  tft.setTextColor(TFT_BLACK);

  if (DISP_GRID) {
    int incr = 10;
    for (int i = 0; i < 128; i = i + incr)
    {
      tft.drawLine(0, i, 159, i, TFT_GREEN);
    }
    for (int i = 0; i < 160; i = i + incr)
    {
      tft.drawLine(i, 0, i, 127, TFT_GREEN);
    }

    int d = 38;
    tft.drawRect(10,  4, d, d, TFT_RED);
    tft.drawRect(10, 50, d, d, TFT_RED);

    tft.drawRect(50,  4, 100, d, TFT_RED);
    tft.drawRect(50, 50, 100, d, TFT_RED);

    tft.drawRect(10, 100, 60, 22, TFT_RED);
    tft.drawRect(90, 100, 60, 22, TFT_RED);

  }

  drawBmp(tft, icon, 11, 5);
  drawBmp(tft, "in_d.bmp",  12, 53);

  tft.drawLine(15, 92, 144, 92, TFT_BLUE);
  tft.drawLine(15, 93, 144, 93, TFT_BLUE);

  tft.loadFont(FONT_LARGE);
  tft.setTextDatum(TR_DATUM);
  tft.drawString(outTemp, 150,  7);
  tft.drawString(inTemp,  150, 53);
  tft.unloadFont();

  tft.loadFont(FONT_MIDDLE);
  tft.drawString(timebuf, 70, 98);
  tft.setTextDatum(TL_DATUM);
  tft.drawString(datebuf, 90, 98);
  tft.unloadFont();
}

void update();
void fetchWeatherData();
void setupDisplay();
void updateDisplay();

Ticker timer1(update, updateSensorsTimeout * 1000);
Ticker timer2(fetchWeatherData, updateWeatherForecastTimeout * 1000);

void addr2hex(const uint8_t* da, char hex[17]) {
  snprintf(hex, 17, "%02X%02X%02X%02X%02X%02X%02X%02X", da[0], da[1], da[2], da[3], da[4], da[5], da[6], da[7]);
}

uint8_t numberOfSensors() {
  uint8_t idx = 0;
  while (sensors[idx].id.length() > 0 && idx < MAX_SENSORS) {++idx;}
  return idx;
}

void addSensor(const String& id, const String& type, const String& measurand) {
  uint8_t idx = 0;
  while (sensors[idx].id.length() > 0 && idx < MAX_SENSORS) {++idx;}
  if (idx < MAX_SENSORS) {
    sensors[idx].enabled = false;
    sensors[idx].id = id;
    sensors[idx].type = type;
    sensors[idx].location = id;
    sensors[idx].topic = id;
    sensors[idx].measurand = measurand;
    sensors[idx].value = "?";
    debug_println("Add "+type+" sensor("+id+")");
  }
}

String getSensorLocation(const String& id) {
  uint8_t idx = 0;
  while (!sensors[idx].id.equals(id) && idx < MAX_SENSORS) {++idx;}
  return (idx < MAX_SENSORS) ? sensors[idx].location : ""; 
}

SensorData& getSensorData(const String& id) {
  uint8_t idx = 0;
  while (!sensors[idx].id.equals(id) && idx < MAX_SENSORS) {++idx;}
  return idx < MAX_SENSORS ? sensors[idx] : tmpSensor;
}

void updateSensorTopic(const String& id) {
  getSensorData(id).topic = rootTopic + "." + getSensorData(id).location;
  getSensorData(id).topic.replace(".", "/");
  debug_println("-> Sensor("+id+").topic = '"+getSensorData(id).topic+"'");
}

void updateSensorTopics() {
  uint8_t idx = 0;
  debug_println("Update sensor topics with rootTopic: " + rootTopic);
  while (sensors[idx].id.length() > 0 && idx < MAX_SENSORS) {
    updateSensorTopic(sensors[idx].id);
    ++idx;
  }
}

void setSensorDataValue(const String& id, float v) {
  SensorData &sd = getSensorData(id);
  sd.value = String(v + sd.correction, 2);
}

void fetchSensorValues() {
  // request to all devices on the bus
  dsSensors.requestTemperatures();

  for (uint8_t i = 0; i < oneWireDeviceCount; ++i) {
    float tempC = dsSensors.getTempC(sensors[i].addr);
    setSensorDataValue(sensors[i].id, tempC);
  }

  if (bmeAddr.length() > 0) {
    setSensorDataValue(bmeAddr+"t",bme.readTemperature());
    setSensorDataValue(bmeAddr+"h",bme.readHumidity());
    setSensorDataValue(bmeAddr+"p",bme.seaLevelForAltitude(nodeAltitude, bme.readPressure()));
  }

  if (si70xxAddr.length() > 0) {
    setSensorDataValue(si70xxAddr+"h",si70xx.readHumidity());
    setSensorDataValue(si70xxAddr+"t",si70xx.readTemperature());
  }

  if (htu21Addr.length() > 0) {
    setSensorDataValue(htu21Addr+"h",htu21.readHumidity());
    setSensorDataValue(htu21Addr+"t",htu21.readTemperature());
  }

  setSensorDataValue(ANALOG_SENSOR_ADDR, 1.0 * analogRead(A0));
}

uint16_t getPayload(char payload[]) {
  uint16_t index=0;
  while (espClient.connected() && espClient.available()) {
    if (index < PAYLOAD_BUFFER_SIZE - 1) {
      int c = espClient.read();
      if (c >= 32) {
        payload[index++] = (char) c;
      } else if (c == '\n') {
        payload[index++] = (char) c;
      }   
    }
  }
  payload[index] = '\0';
  return index;
}

void printKV(const String& k, const String& v) {
  espClient.print("\"");
  espClient.print(k);
  espClient.print("\":\"");
  espClient.print(v);
  espClient.print("\"");
}

String findData(const String& line, const String& key) {
  int sIndex = line.indexOf(key+"=");
  if (sIndex < 0) return "";
  sIndex += (key.length() + 1);

  String result;
  int eIndex = line.indexOf("&", sIndex);
  if (eIndex > 0) {
    result = line.substring(sIndex, eIndex);
  } else {
    result = line.substring(sIndex);
  }
  
  result.trim();
  result.toLowerCase();
  return result;
} 

void writeConfigLine(File& f, const String& line) {
    f.println(line);
    debug_println("<- " + line);
}

void saveConfig() {
  if (!LittleFS.begin()) {
    log(LOGLEVEL_ERROR, F("Error while init LittleFS."));
    return;
  }
  File f = LittleFS.open(CONFIG_FILE, "w");
  if (!f) {
    log(LOGLEVEL_ERROR, F("Open config file to write failed!"));
  } else {
    debug_println("Save config file ... ");

    writeConfigLine(f, "node=" + nodeName);
    writeConfigLine(f, "topic=" + rootTopic);
    writeConfigLine(f, "altitude=" + String(nodeAltitude, 2));
    writeConfigLine(f, "sto=" + String(updateSensorsTimeout, 10));
    writeConfigLine(f, "wfcto=" + String(updateWeatherForecastTimeout, 10));

    if (hasDisplay) {
      writeConfigLine(f, "hasDisplay");
    }
    
    if (showSensor.length() > 0) {
      writeConfigLine(f, "show=" + showSensor);
    }
    
    uint8_t idx = 0;
    while (sensors[idx].id.length() > 0 && idx < MAX_SENSORS) {
      writeConfigLine(f, "sensor-" + sensors[idx].id + "=" + sensors[idx].location);
      writeConfigLine(f, "sensor.enabled-" + sensors[idx].id + "=" + sensors[idx].enabled);
      writeConfigLine(f, "sensor.correction-" + sensors[idx].id + "=" + sensors[idx].correction);
      ++idx;
    }
    
    f.close();
    log(LOGLEVEL_INFO, F("Saved config."));
  }

  LittleFS.end();
}

bool isNewValue(const String& oldValue, const String& newValue) {
  return newValue.length() > 0 && !oldValue.equals(newValue);
}

void handleGetRoot() {
  espServer.send(200, "text/html", configHtml);   
}

void handleGetConfig() {
  snprintf(webSendBuffer, SIZE_WEBSENDBUFFER, 
    "{\"version\":%d,\"build\":\"%s\",\"sensorcycle\":%d,\"forecastcycle\":%d,\"node\":\"%s\",\"topic\":\"%s\",\"altitude\":\"%-.2f\",\"display\":%d}", 
    SENSORNODE_VERSION,
    COMPILE_INFO,
    updateSensorsTimeout,
    updateWeatherForecastTimeout,
    nodeName.c_str(),
    rootTopic.c_str(),
    nodeAltitude,
    hasDisplay
  );
  espServer.send(200, "application/json", webSendBuffer);   
}

void handleGetSensors() {
  strcpy(webSendBuffer, "{");

  char sep[2];
  sep[0]='\0';
  sep[1]='\0';

  char oneSensorBuf[SIZE_JSON_ONE_SENSOR];
  uint8_t idx = 0;
  while (sensors[idx].id.length() > 0 && idx < MAX_SENSORS) {
    snprintf(oneSensorBuf, SIZE_JSON_ONE_SENSOR, 
            //     keys: e, l, t, m, v, c, s
            "%s\"%s\":{\"enabled\":%d,\"location\":\"%s\",\"type\":\"%s\",\"measurand\":\"%s\",\"value\":\"%s\",\"correction\":\"%-.2f\",\"show\":%d}", 
            sep, 
            sensors[idx].id.c_str(), 
            sensors[idx].enabled, 
            sensors[idx].location.c_str(), 
            sensors[idx].type.c_str(), 
            sensors[idx].measurand.c_str(), 
            sensors[idx].value.c_str(),
            sensors[idx].correction,
            showSensor.equals(sensors[idx].id));
    sep[0]=',';
    strncat(webSendBuffer, oneSensorBuf, SIZE_WEBSENDBUFFER - strlen(webSendBuffer));
    ++idx;
  }
  strncat(webSendBuffer, "}", SIZE_WEBSENDBUFFER - strlen(webSendBuffer));
  espServer.send(200, "application/json", webSendBuffer);   
}

void handleGetLogs() {
  int32_t startId = 0;
  if (espServer.args() == 1 && espServer.hasArg("id")) {
    startId = max(espServer.arg(0).toInt(), 0L);
  }
  
  espServer.chunkedResponseModeStart(200, "application/json");
  espServer.sendContent("{\"nextId\":");
  sprintf(logbuf, "%d", lastLogId + 1);
  espServer.sendContent(logbuf);
  espServer.sendContent(",\"logs\":[");
  if (startId <= lastLogId) {
    int8_t cnt = (int8_t) min(lastLogId - startId + 1, LOGLINE_CNT);
    int8_t idx = (lastLogId - cnt) % LOGLINE_CNT;
    char sep[2] = " ";
    char tstamp[9];
    for (uint8_t i = 0; i < cnt; ++i) {
      ++idx;
      if (idx == LOGLINE_CNT) idx = 0;
      if (strlen(logs[idx].message) == 0) continue;

      espServer.sendContent(sep);
      espServer.sendContent("{\"time\":\"");
      snprintf(tstamp, 9, "%02d:%02d:%02d", logs[idx].timestamp[0], logs[idx].timestamp[1], logs[idx].timestamp[2]);
      espServer.sendContent(tstamp);
      espServer.sendContent("\",\"level\":\"");
      switch(logs[idx].level) {
        case LOGLEVEL_ERROR: espServer.sendContent("ERROR"); break;
        case LOGLEVEL_WARN: espServer.sendContent("WARN"); break;
        case LOGLEVEL_INFO: espServer.sendContent("INFO"); break; 
        default: espServer.sendContent("DEBUG");
      }
      espServer.sendContent("\",\"msg\":\"");
      espServer.sendContent(logs[idx].message);
      espServer.sendContent("\"}");
      sep[0] = ',';
    }
  }
  espServer.sendContent("]}");
  espServer.chunkedResponseFinalize();
}

// POST new node name and/or a new sensor location
void handlePostRoot() {
  String content = espServer.arg("plain");
  debug_println("Request content: '" + content + "'");

  bool needSave = false;
  bool needSensorFetch = false;
  String newValue;

  newValue = findData(content, "node"); 
  if (isNewValue(nodeName, newValue)) {
    nodeName = newValue;
    needSave = true;
  }

  newValue = findData(content, "topic");
  if (isNewValue(rootTopic, newValue)) {
    rootTopic = newValue;
    updateSensorTopics();
    needSave = true;
  }

  newValue = findData(content, "altitude");
  if (isNewValue(String(nodeAltitude, 2), newValue)) {
    nodeAltitude = newValue.toFloat();
    needSensorFetch = true;
    needSave = true;
  }

  newValue = findData(content, "sensorcycle");
  if (isNewValue(String(updateSensorsTimeout, 10), newValue)) {
    updateSensorsTimeout = max(1L,newValue.toInt());
    timer1.interval(updateSensorsTimeout * 1000);
    needSave = true;
  }

#if SENSORNODE_VERSION >= SENSORNODE_WITH_DISPLAY_VERSION
  newValue = findData(content, "forecastcycle");
  if (isNewValue(String(updateWeatherForecastTimeout, 10), newValue)) {
    updateWeatherForecastTimeout = newValue.toInt();
    timer2.interval(updateWeatherForecastTimeout * 1000);
    needSave = true;
  }

  newValue = findData(content, "hasDisplay");
  if (hasDisplay != (newValue.length() > 0)) {
    hasDisplay = newValue.length() > 0;
    needSave = true;
    setupDisplay();
  }
#else
  hasDisplay = false;
#endif

  uint8_t idx = 0;
  while (sensors[idx].id.length() > 0 && idx < MAX_SENSORS) {
    String key = "loc-" + sensors[idx].id;
    newValue = findData(content, key);
    if (isNewValue(sensors[idx].location, newValue)) {
      sensors[idx].location = newValue;
      updateSensorTopic(sensors[idx].id);
      needSave = true;
    }

    key = "en-" + sensors[idx].id;
    newValue = findData(content, key);
    bool newEnabled = newValue.equals("on");
    needSave = needSave || (sensors[idx].enabled == newEnabled);
    sensors[idx].enabled = newEnabled;

    key = "cor-" + sensors[idx].id;
    newValue = findData(content, key);
    if (isNewValue(String(sensors[idx].correction, 2), newValue)) {
      sensors[idx].correction = newValue.toFloat();
      needSave = true;
      needSensorFetch = true;
    }

    key = "show";
    newValue = findData(content, key);
    if (isNewValue(showSensor, newValue)) {
      showSensor = newValue;
      needSave = true;
    }

    ++idx;
  }

  if (needSave) saveConfig();
  if (needSensorFetch) fetchSensorValues();
  
  if (needSave || needSensorFetch) updateDisplay();

  espServer.sendHeader("Location", "/");
  espServer.send(303);
}

void handleError() {
  espServer.send(404, "text/plain", "404: Not found");
}

void loadConfigHtml() {
  configHtml = "";
  File f = LittleFS.open(CONFIG_HTML, "r");
  if (!f) {
    log(LOGLEVEL_ERROR,F("HTML file not found/open failed"));
    configHtml = "HTML file not found/open failed";
  } else {
    while(f.available()) {
      configHtml = configHtml + f.readString();
    }
    f.close();
  }
}
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
void loop(void) { 
  ArduinoOTA.handle();
  espServer.handleClient();

  if (!mqttClient.connected()) {
    mqttReconnect();
  }
  mqttClient.loop();

  timer1.update(); 
  timer2.update(); 
 }

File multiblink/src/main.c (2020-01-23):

/*
 * File:   main.c
 * Author: thomo
 *
 * Created on January 19, 2020, 12:12 PM
 */


#include <xc.h>
#include <stdint.h>        /* For uint8_t definition */
#include <stdbool.h>       /* For true/false definition */

#include "system.h"        /* System funct/params, like osc/peripheral config */
#include "user.h"          /* User funct/params, such as InitApp */

/******************************************************************************/
/* User Global Variable Declaration                                           */
/******************************************************************************/

/******************************************************************************/
/* Main Program                                                               */
/******************************************************************************/

void main(void)
{
    /* Configure the oscillator for the device */
    ConfigureOscillator();

    /* Initialize I/O and Peripherals for application */
    InitApp();


    while(1)
    {
        LoopApp();
    }

}

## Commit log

2019-03-30 cyclic acquisition of sensor data
2019-03-31 replace location by node, introduce measurand
    [main.cpp]
2019-04-01 prepare sensor output
2019-04-01 use sensor location instead of sensor name
2019-04-01 append topic to SensorData
2019-04-07 store and update roottopic in sensortopic
2019-04-07 publish sensor data by mqtt
2019-04-13 add enabled flag to sensors
2019-04-13 redesign form and load/save enable flag
    [main.cpp]
2019-04-27 fix load config issue
    [main.cpp]
2019-04-28 add pcb stuff and begin with docu
    [SensorNodeUsb.brd, SensorNodeUsb.sch]
2019-05-01 modify adjust a part name and a part value
    [SensorNodeUsb.brd, SensorNodeUsb.sch]
2019-05-01 remove 2 vias near R2
    [SensorNodeUsb.brd]
2019-05-01 rename circuit file
2019-05-01 add SensorNodeUsb circuit and board description and image links
2019-06-18 add internal temp sensor to available sensors
2019-07-13 5-pin programming interface
    [SensorNodeUsb.brd, SensorNodeUsb.sch]
2019-07-14 change programming interface
    [SensorNodeUsb.brd, SensorNodeUsb.sch]
2019-07-14 change a message and increase max no. of sensors
2019-07-23 initial config file (intentionally empty)
    [config.cfg]
2019-07-23 init topic field in sensors array
2019-07-23 change max number of sensors
2019-07-24 add 3d model of usb spacer plate
    [usbspacer.blend, usbspacer.stl]
2019-07-27 rename deviceCount variable to oneWireDeviceCount
2019-07-28 place values on board
    [SensorNodeUsb.brd]
2019-07-28 add correction values and configurable altitude
    [main.cpp]
2020-01-23 SensorHub PCB files
    [SensorHub.brd, SensorHub.sch]
2020-01-23 CatNode pcb files
    [CatNode.brd, CatNode.sch]
2020-09-20 sensor hub with power lines only
    [SensorHub.brd, SensorHub.sch]
2020-10-16 add SensorNodeCat board
    [SensorNodeCat.brd, SensorNodeCat.sch]
2020-10-16 add Sensor type HTU21
2020-10-17 further boards
2020-11-01 Add flag for different board layouts
2020-11-01 Introduce SENSORNODE_VERSION
2021-01-02 add resistor parallel to LDR
    [SensorNodeCat.brd, SensorNodeCat.sch]
2021-01-03 add LDR and text to PCB
    [SensorNodeCat.brd, SensorNodeCat.sch]
2021-01-03 Fix config file log msg.
    [main.cpp]
2021-01-30 Add notes about SensorNodeCat.
2023-03-22 update libs
    [SensorNodeWithDisplay.brd, SensorNodeWithDisplay.sch]
2025-11-09 RSSI sensor

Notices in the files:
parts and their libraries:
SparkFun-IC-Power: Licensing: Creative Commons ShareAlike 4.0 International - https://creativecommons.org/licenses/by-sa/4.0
